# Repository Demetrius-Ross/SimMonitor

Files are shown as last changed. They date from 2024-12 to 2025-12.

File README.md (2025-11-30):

# SimMonitoring Overview WIP
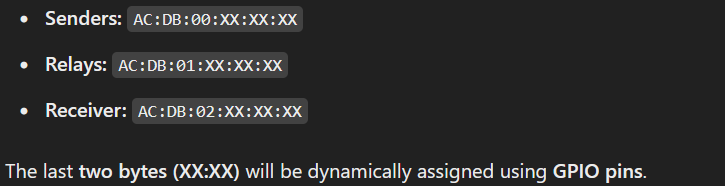
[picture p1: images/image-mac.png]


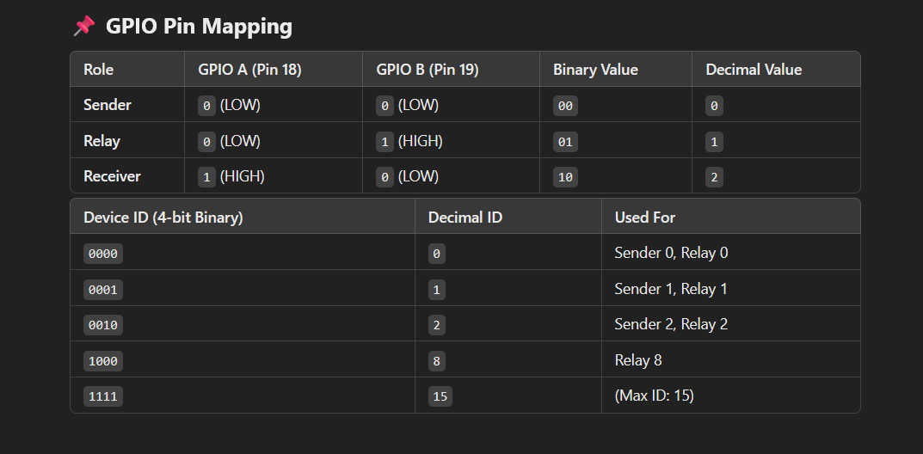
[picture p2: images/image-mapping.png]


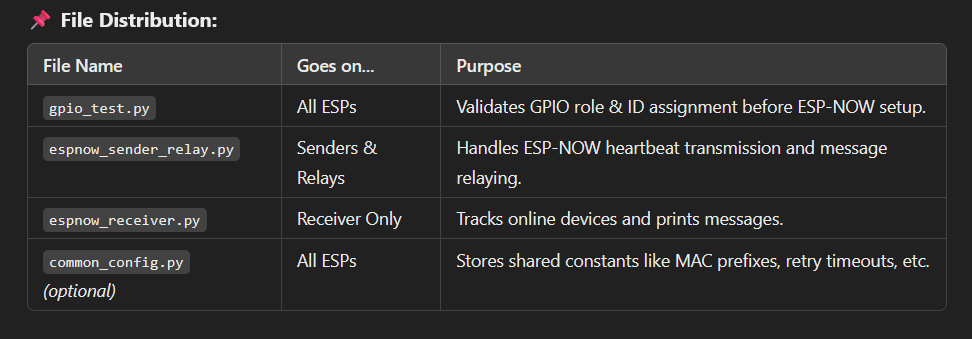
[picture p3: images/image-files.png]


Rename the main script to main.py
'''bash
mv espnow_sender_relay.py main.py
'''

Flash it to the ESP32:
'''bash
mpremote connect /dev/ttyUSB0 fs cp main.py :
'''

Reset the ESP32 to run it automatically:
'''bash
mpremote connect /dev/ttyUSB0 reset
'''

If you want manual execution, you can run any script interactively:
'''bash
mpremote connect /dev/ttyUSB0 run gpio_test.py
'''

## Wiring Guide for Each ESP32 Device

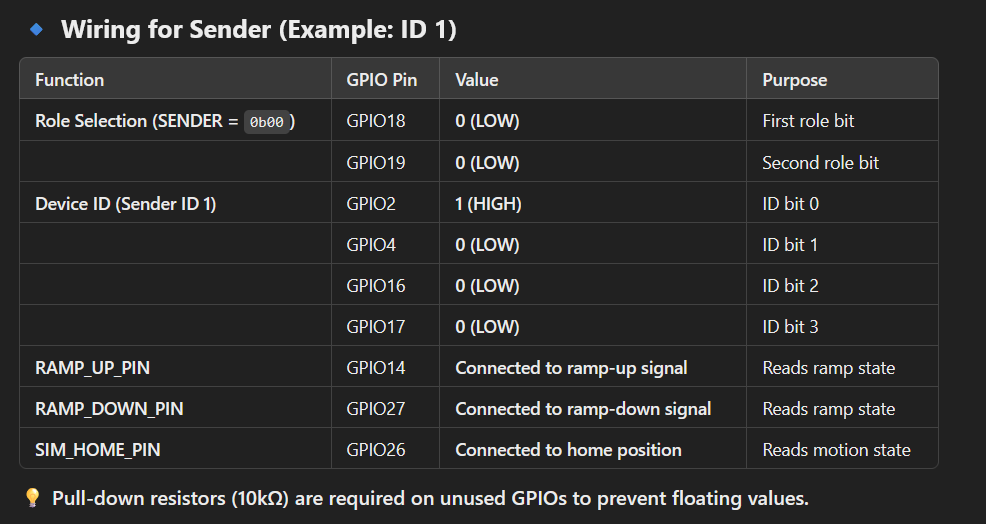
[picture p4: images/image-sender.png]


# ESP32 Device ID Configuration for Sender

Below is a quick reference for how to wire **GPIO17**, **GPIO16**, **GPIO4**, and **GPIO2** to assign a **device ID** (0–15). Each pin is interpreted as a bit in the 4-bit ID, read in the order `(Pin2=bit0, Pin4=bit1, Pin16=bit2, Pin17=bit3)`.

| Device ID | Binary (bit3..bit0) | Pin17 (bit3) | Pin16 (bit2) | Pin4 (bit1) | Pin2 (bit0) |
|---|---|---|---|---|---|
| **0** | `0000` | 0 (LOW) | 0 (LOW) | 0 (LOW) | 0 (LOW) |
| **1** | `0001` | 0 (LOW) | 0 (LOW) | 0 (LOW) | 1 (HIGH) |
| **2** | `0010` | 0 (LOW) | 0 (LOW) | 1 (HIGH) | 0 (LOW) |
| **3** | `0011` | 0 (LOW) | 0 (LOW) | 1 (HIGH) | 1 (HIGH) |
| **4** | `0100` | 0 (LOW) | 1 (HIGH) | 0 (LOW) | 0 (LOW) |
| **5** | `0101` | 0 (LOW) | 1 (HIGH) | 0 (LOW) | 1 (HIGH) |
| **6** | `0110` | 0 (LOW) | 1 (HIGH) | 1 (HIGH) | 0 (LOW) |
| **7** | `0111` | 0 (LOW) | 1 (HIGH) | 1 (HIGH) | 1 (HIGH) |
| **8** | `1000` | 1 (HIGH) | 0 (LOW) | 0 (LOW) | 0 (LOW) |
| **9** | `1001` | 1 (HIGH) | 0 (LOW) | 0 (LOW) | 1 (HIGH) |
| **10** | `1010` | 1 (HIGH) | 0 (LOW) | 1 (HIGH) | 0 (LOW) |
| **11** | `1011` | 1 (HIGH) | 0 (LOW) | 1 (HIGH) | 1 (HIGH) |
| **12** | `1100` | 1 (HIGH) | 1 (HIGH) | 0 (LOW) | 0 (LOW) |
| **13** | `1101` | 1 (HIGH) | 1 (HIGH) | 0 (LOW) | 1 (HIGH) |
| **14** | `1110` | 1 (HIGH) | 1 (HIGH) | 1 (HIGH) | 0 (LOW) |
| **15** | `1111` | 1 (HIGH) | 1 (HIGH) | 1 (HIGH) | 1 (HIGH) |

## Notes

1. **GPIO2** is the **least significant bit** (bit0).  
2. **GPIO17** is the **most significant bit** (bit3).  
3. Use **10kΩ resistors** (or internal pulls) to pull each pin HIGH or LOW.  
4. For a **Sender** role, set **GPIO18 = 0 (LOW)** and **GPIO19 = 0 (LOW)**. This yields `role_value = 0` => `"SENDER"`.

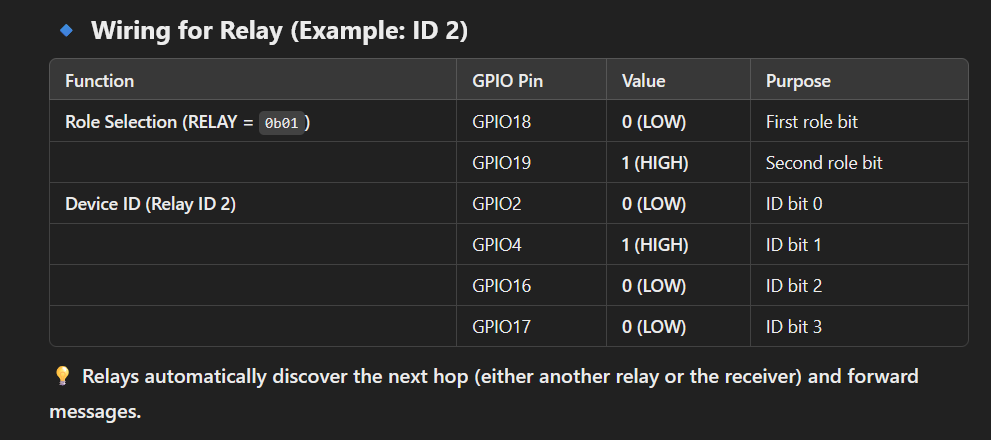
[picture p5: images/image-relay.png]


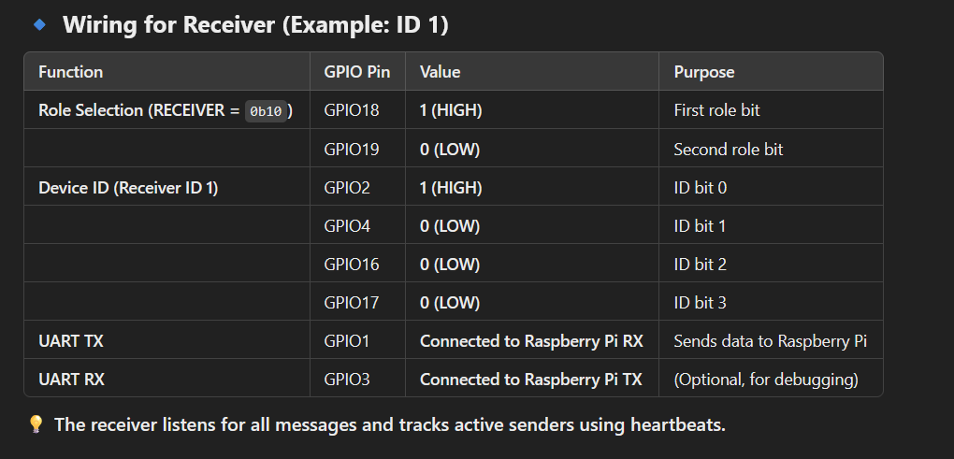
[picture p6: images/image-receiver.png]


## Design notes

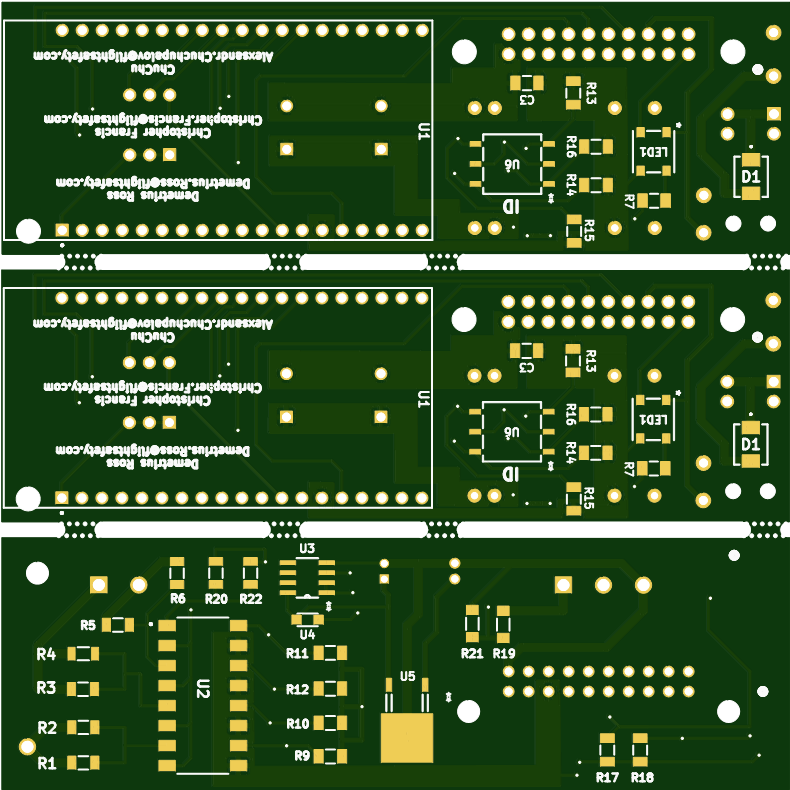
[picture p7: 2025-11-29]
Hardware-Design/gerber-files/panel-boards/Untitled_Combined_Bottom.png

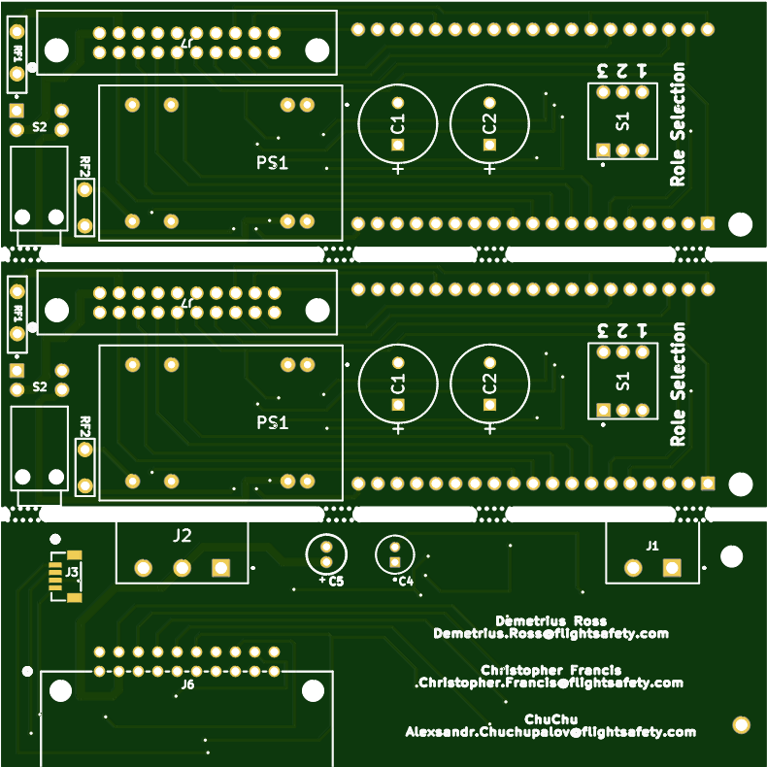
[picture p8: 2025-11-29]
Hardware-Design/gerber-files/panel-boards/Untitled_Combined_Top.png

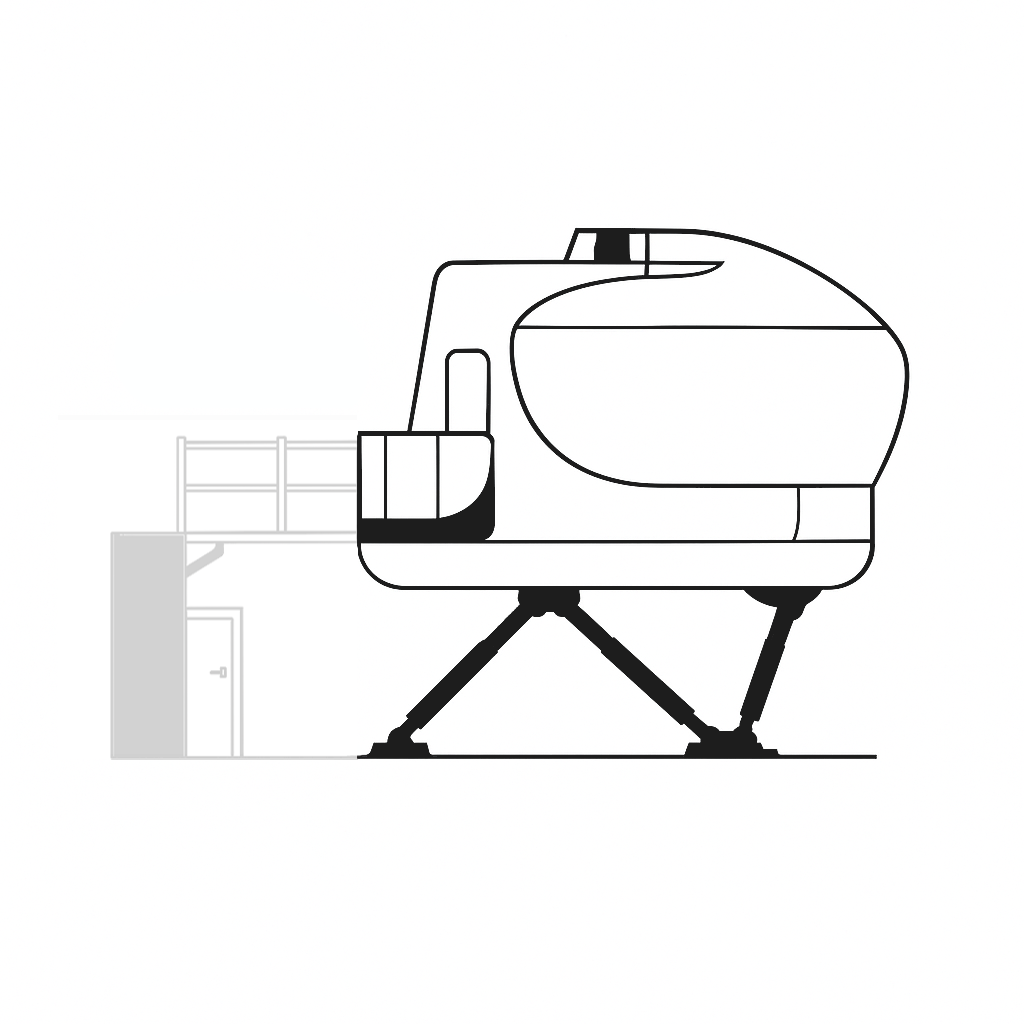
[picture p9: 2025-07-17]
sim_monitor/BACKUP-V1.1/images/FINAL-SIM-DOWN-NO-RAMP.png

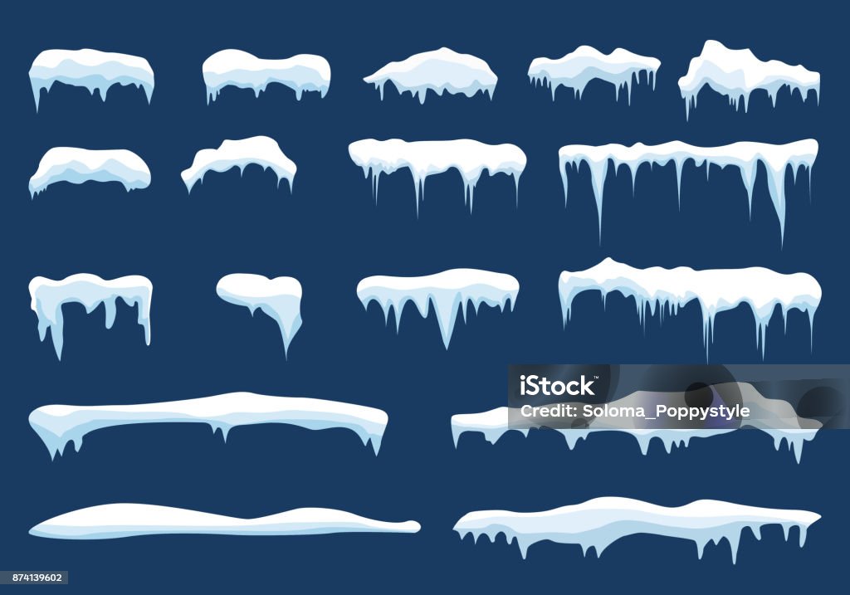
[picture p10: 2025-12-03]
images/istockphoto-874139602-1024x1024.jpg

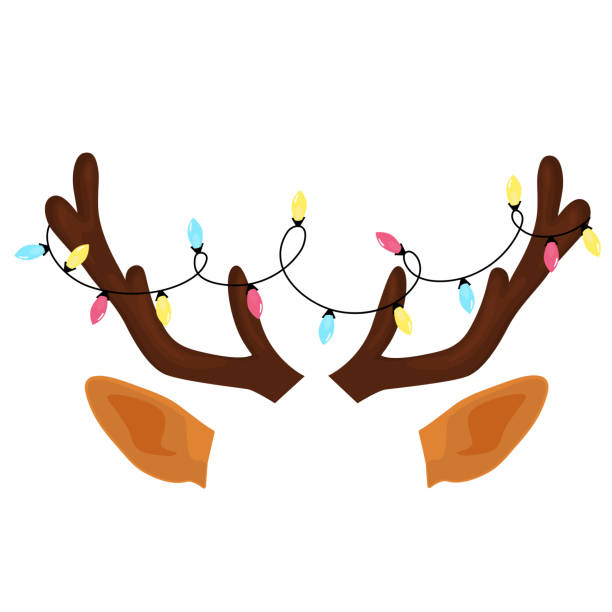
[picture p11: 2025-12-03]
images/istockphoto-1287654583-612x612.jpg

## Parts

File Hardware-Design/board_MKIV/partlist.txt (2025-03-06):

Parts List:
DC-DC Converter: MUS-2405-2N
$4.26
4369-MUS-2405-2N-ND

SMD Version:	
(DC-DC Converter) Buck Switching Regulator IC Positive: MP2315SGJ-Z
$2.92

Schottky Diode: SS14
$0.29

(4 Channel Optocoupler) TLP291-4(GB-TP,E)
$1.42

(24v Ceramic Capacitor) CL31A226KAHNNNE (22)
$0.22

(5v Ceramic Capacitor) CL31B106KAHNNNE 
$0.15

(Decoupling Capacitor) C1206C104K4RACTU (0.1)
Quantity: 2
Total Price: $0.20

Resistors: 

Current-limiting resistors for optocoupler LEDs: CR1206-FX-2200ELF (220Ω)
Quantity: 3
Total Price: $0.30

Pull-down resistors for ESP32 GPIOs: CR1206-FX-1002ELF (10kΩ)
Quantity: 3
Total Price: $0.30

LED current-limiting resistors: CR1206-FX-4700ELF (470Ω)
Quantity: 3
Total Price: $0.30

EN Pin Resistors:

RC1206FR-07499KL (499KΩ)
$0.10

FB Resistor:
RC1206FR-07100KL (100KΩ)
$0.10

CR1206-FX-3002ELF (30KΩ)
$0.10

C1206C104K4RACTU (0.1 µF)
$0.10

Inductor:
HPC 6045NC-4R7M
$0.18

Rotary Switch: RDS-16S-1055-D
$2.41

or 
DRR 3016/RTE1602V44
$3.09/$2.94

=====================================================================================================================================================

Cannon Plug
RS232

2.2k OHM to optocoupler

Component					Value for 5V Output		Purpose
R1 (Feedback Resistor)				40.2kΩ				Sets output voltage
R2 (Feedback Resistor)				7.5kΩ				Sets output voltage
R3 (BST Resistor)				10Ω				Limits bootstrap current
R4 (AAM Resistor 1)				100kΩ				Sets AAM voltage divider
R5 (AAM Resistor 2)				20kΩ				Sets AAM voltage divider
R6 (Optional - Additional FB Tuning Resistor)	20kΩ				Enhances transient response
R7 (EN Voltage Divider Resistor 1)		220kΩ				Steps down 24V to ~1.5V for EN
R8 (EN Voltage Divider Resistor 2)		15kΩ				Works with R7 to set EN voltage
L1 (Inductor)					4.7µH - 10µH, ≥3A		Filters current and maintains switching
C1 (Input Capacitor)				22µF 25V X5R			Stabilizes 24V input
C1A (Input Filter Capacitor)			0.1µF				Reduces input noise
C2 (Output Capacitor)				22µF 25V X7R			Stabilizes 5V output
C2A (Second Output Capacitor)			22µF 25V X7R			Reduces ripple at 5V output
C3 (BST Capacitor)				0.1µF				Provides gate drive voltage boost
C4 (AAM Capacitor)				0.1µF				Smooths AAM voltage
C5 (Compensation Capacitor - Optional)		33pF				Improves transient response
D1 (Bootstrap Diode - Optional)			1N4148				Increases efficiency
D2 (Schottky Diode)				SS14 (40V, 1A)			Provides freewheeling path for current

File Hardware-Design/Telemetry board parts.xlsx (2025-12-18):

MXC6655XA Memsic Inc. | Sensors, Transducers | DigiKey (https://www.digikey.com/en/products/detail/memsic-inc/MXC6655XA/12171923) | $0.94 | 10.00 | 3, 2.7K Ohm, 1, 4.7 MicroFerd Cap | Microsoft Word - MXC6655XA Datasheet Rev A (https://mm.digikey.com/Volume0/opasdata/d220001/medias/docus/495/MXC6655XA_Rev_A_1-22-20.pdf)
TMP112D3IDPWR Texas Instruments | Sensors, Transducers | DigiKey (https://www.digikey.com/en/products/detail/texas-instruments/TMP112D3IDPWR/24768881) | $0.46 |  | 3, 5k resistors and 10 NanoFerd Cap | TMP112x High-Accuracy, Low-Power, Digital Temperature Sensors With SMBus and Two-Wire Serial Interface in SOT563 and X2SON Packages datasheet (Rev. L) (https://www.ti.com/lit/ds/symlink/tmp112.pdf?ts=1626246186568)
ZRE200GE Zilog | Sensors, Transducers | DigiKey (https://www.digikey.com/en/products/detail/zilog/ZRE200GE/5147335) | $1.10 |  | 47K Ohms | PS0402.pdf (https://www.zilog.com/docs/zmotion/PS0402.pdf)
3A0231212A Sensata Technologies | Sensors, Transducers | DigiKey (https://www.digikey.com/en/products/detail/sensata-technologies/3A0231212A/8558165) | $20.00
Amazon.com: GeeekPi GPIO Expansion Module with 3.5inch Screen for Raspberry Pi Pico 1/Pico 1 W and Raspberry Pi Pico 2 Series : Electronics (https://www.amazon.com/GeeekPi-Expansion-Module-3-5inch-Raspberry/dp/B0C98G37PW)
Amazon.com: YELUFT 2 Pack Pre-Soldered ESP32 LoRa V4 Development Board with 915MHz LoRa Antenna, Integrated WiFi Bluetooth SX1262 0.96-inch OLED Display Type C Interface for Meshtastic Arduino : Electronics (https://www.amazon.com/dp/B0FSJLFQTN?sp_csd=d2lkZ2V0TmFtZT1zcF9kZXRhaWw)
STEVAL-STLCS01V1 STMicroelectronics | Development Boards, Kits, Programmers | DigiKey (https://www.digikey.com/en/products/detail/stmicroelectronics/STEVAL-STLCS01V1/7164223)

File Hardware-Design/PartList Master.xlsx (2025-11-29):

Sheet: Sheet1
Sim Monitor Board Component List
Part | DigiKey Name | QTY | Price Per Component | Total Price of Item | Link | Notes
4.7 kOhms Chip Resistor | CRGH1206J4K7 | 8 | $0.14 | $1.12 | CRGH1206J4K7 TE Connectivity Passive Product | Resistors | DigiKey (https://www.digikey.com/en/products/detail/te-connectivity-passive-product/CRGH1206J4K7/2385708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)
10 kOhm Chip Resistor | CR1206-FX-1002ELF | 10 | $0.10 | $1.00 | CR1206-FX-1002ELF Bourns Inc. | Resistors | DigiKey (https://www.digikey.com/en/products/detail/bourns-inc/CR1206-FX-1002ELF/2562678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)
Rotary Hex Switch | DRR3016 | 1 | $3.08 | $3.08 | DRR 3016 Knitter-Switch | Switches | DigiKey (https://www.digikey.com/en/products/detail/knitter-switch/DRR-3016/15296328?s=N4IgTCBcDaICICUEGYAMBGAbCAugXyA)
Optocoupler | 160-1365-5-ND | 1 | $0.90 | $0.90 | LTV-846S Lite-On Inc. | Isolators | DigiKey (https://www.digikey.com/en/products/detail/liteon/LTV-846S/385835?s=N4IgTCBcDaIIwDYAMBaOBmBBWFOByAIiALoC%2BQA)
JST Connector Header | S3B-EH | 1 | $0.11 | $0.11 | S3B-EH JST Sales America Inc. | Connectors, Interconnects | DigiKey (https://www.digikey.com/en/products/detail/jst-sales-america-inc/S3B-EH/926534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)
Schottky Diode | SS34B-HF | 1 | $0.27 | $0.27 | SS34B-HF Comchip Technology | Discrete Semiconductor Products | DigiKey (https://www.digikey.com/en/products/detail/comchip-technology/SS34B-HF/12326213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)
1000 pF (3kV) Ceramic Cap | VPDD302W102K1GV001E | 1 | $0.58 | $0.58 | VPDD302W102K1GV001E Johanson Dielectrics Inc. | Capacitors | DigiKey (https://www.digikey.com/en/products/detail/johanson-dielectrics-inc/VPDD302W102K1GV001E/21283574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)
QWIIC Connector Header | 1568-16766-ND | 1 | $0.75 | $0.75 | 16766 SparkFun Electronics | Connectors, Interconnects | DigiKey (https://www.digikey.com/en/products/detail/sparkfun-electronics/16766/12340136)
JST Female Socket | 455-2935-ND | 1 | $0.18 | $0.18 | 03HR-4K-P-N JST Sales America Inc. | Connectors, Interconnects | DigiKey (https://www.digikey.com/en/products/detail/jst-sales-america-inc/03HR-4K-P-N/1555744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)
47 uF (100V) Electrolytic Cap | UHE2A470MPD | 2 | $0.56 | $1.12 | UHE2A470MPD Nichicon | Capacitors | DigiKey (https://www.digikey.com/en/products/detail/nichicon/UHE2A470MPD/589404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)
D-Sub Female Through Hole | A-DF 09 A/KG-T4S | 1 | $0.72 | $0.72 | A-DF 09 A/KG-T4S Assmann WSW Components | Connectors, Interconnects | DigiKey (https://www.digikey.com/en/products/detail/assmann-wsw-components/A-DF-09-A-KG-T4S/1241802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)
3 Pos Male Block Header | 1757255 | 1 | $1.26 | $1.26 | 1757255 Phoenix Contact | Connectors, Interconnects | DigiKey (https://www.digikey.com/en/products/detail/phoenix-contact/1757255/260475?s=N4IgTCBcDaIIwHYCsCxKSAugXyA)
ISO DC-DC Converter 5V | REC5A-2405SW/H2 | 1 | $14.82 | $14.82 | REC5A-2405SW/H2 Recom Power | Power Supplies - Board Mount | DigiKey (https://www.digikey.com/en/products/detail/recom-power/REC5A-2405SW-H2/6483546)
PTC Reset Fuse 1.1 A | RXEF110-ND | 1 | $0.56 | $0.56 | RXEF110 Littelfuse Inc. | Circuit Protection | DigiKey (https://www.digikey.com/en/products/detail/littelfuse-inc/RXEF110/1045810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) | Backorder
PTC Reset Fuse 500 mA | RXEF050-2HFCT-ND | 1 | $0.54 | $0.54 | RXEF050-2 Littelfuse Inc. | Circuit Protection | DigiKey (https://www.digikey.com/en/products/detail/littelfuse-inc/RXEF050-2/5016000)
ESP32 | ESP32-DEVKITC-32E | 1 | $10 | $10.00 | ESP32-DEVKITC-32E Espressif Systems | Development Boards, Kits, Programmers | DigiKey (https://www.digikey.com/en/products/detail/espressif-systems/ESP32-DEVKITC-32E/12091810)
Total Cost of Components |  |  |  | $37.01
Board Cost (PCB Way @ 10 Boards) |  | QTY: 1 | $0.65
Total |  |  |  | $37.66

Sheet: Sheet2
Part | DigiKey Name | QTY | Price Per Component | Total Price of Item | Link | Notes
Op Amp | TLV272CDR | 10 | $0.71 | $7.06 | TLV272CDR Texas Instruments | Integrated Circuits (ICs) | DigiKey (https://www.digikey.com/en/products/detail/texas-instruments/TLV272CDR/1677979)
1 MOhms ±5% 0.667W, 2/3W Chip Resistor 1206 | ERJ-P08J105V | 50 | $0.05 | $2.36 | ERJ-P08J105V Panasonic Electronic Components | Resistors | DigiKey (https://www.digikey.com/en/products/detail/panasonic-electronic-components/ERJ-P08J105V/525320)
470 Ohms ±1% 0.25W, 1/4W Chip Resistor 1206 | CRG1206F470R | 50 | $0.03 | $1.39 | CRG1206F470R TE Connectivity Passive Product | Resistors | DigiKey (https://www.digikey.com/en/products/detail/te-connectivity-passive-product/CRG1206F470R/2381011)
BAT46W | DIODE SCHOTTKY 100V 150MA SOD123 | 10 | $0.10 | $0.99 | BAT46W Diotec Semiconductor | Discrete Semiconductor Products | DigiKey (https://www.digikey.com/en/products/detail/diotec-semiconductor/BAT46W/13156682)
330 kOhms ±5% 0.667W, 2/3W Chip Resistor 1206 | ERJ-P08J334V | 50 | $0.05 | $2.36 | ERJ-P08J334V Panasonic Electronic Components | Resistors | DigiKey (https://www.digikey.com/en/products/detail/panasonic-electronic-components/ERJ-P08J334V/525379)
10 µF 50 V Aluminum Electrolytic Capacitors Radial | ECA-1HM100 | 10 | $0.12 | $1.21 | ECA-1HM100 Panasonic Electronic Components | Capacitors | DigiKey (https://www.digikey.com/en/products/detail/panasonic-electronic-components/ECA-1HM100/245037)
10 µF 25 V Aluminum Electrolytic Capacitors Radial | 860020472003 | 10 | $0.10 | $1.00 | 860020472003 Würth Elektronik | Capacitors | DigiKey (https://www.digikey.com/en/products/detail/w%C3%BCrth-elektronik/860020472003/5727057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)
Linear Voltage Regulator IC Positive Fixed | BA7815FP-E2 | 10 | $0.77 | $7.72 | BA7815FP-E2 Rohm Semiconductor | Integrated Circuits (ICs) | DigiKey (https://www.digikey.com/en/products/detail/rohm-semiconductor/BA7815FP-E2/2357085)
CONN DIN HDR 20POS | PCN10-20P-2.54DS(72) | 10 | $2.59 | $25.92 | PCN10-20P-2.54DS(72) Hirose Electric Co Ltd | Connectors, Interconnects | DigiKey (https://www.digikey.com/en/products/detail/hirose-electric-co-ltd/PCN10-20P-2-54DS-72/1036416)
CONN DIN RCPT 20POS | PCN13-20S-2.54DSA(71) | 10 | $2.22 | $22.17 | PCN13-20S-2.54DSA(71) Hirose Electric Co Ltd | Connectors, Interconnects | DigiKey (https://www.digikey.com/en/products/detail/hirose-electric-co-ltd/PCN13-20S-2-54DSA-71/1036454)
2 Position Terminal Block Header, Male Pins, Shrouded | 1757242 | 10 | $0.82 | $5.95 | 1757242 Phoenix Contact | Connectors, Interconnects | DigiKey (https://www.digikey.com/en/products/detail/phoenix-contact/1757242/260474)
2 Position Terminal Block Plug, Female Sockets | 1757019 | 10 | $1.69 | $16.88 | 1757019 Phoenix Contact | Connectors, Interconnects | DigiKey (https://www.digikey.com/en/products/detail/phoenix-contact/1757019/260379)
330 mOhms Resistor | CRL1206-FW-R330ELF | 50 | $0.07 | $3.42 | CRL1206-FW-R330ELF Bourns Inc. | Resistors | DigiKey (https://www.digikey.com/en/products/detail/bourns-inc/CRL1206-FW-R330ELF/3785728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)
SWITCH SLIDE DIP SPST 0.025A 24V | DS01C-254-S-03BE | 20 | $0.51 | $10.20 | DS01C-254-S-03BE Same Sky (Formerly CUI Devices) | Switches | DigiKey (https://www.digikey.com/en/products/detail/same-sky-formerly-cui-devices/DS01C-254-S-03BE/11310944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)
SW ROTARY DIP HEX COMP 0.1A 5V | SH-7070TB | 20 | $2.54 | $25.35 | SH-7070TB Nidec Components Corporation | Switches | DigiKey (https://www.digikey.com/en/products/detail/nidec-components-corporation/SH-7070TB/2057875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)
SWITCH PB DPST 3A 30V | PB400EEQR1BLK | 20 | $1.92 | $28.38 | PB400EEQR1BLK E-Switch | Switches | DigiKey (https://www.digikey.com/en/products/detail/e-switch/PB400EEQR1BLK/8042726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)
 |  | Total: | $9.24 | $95.01

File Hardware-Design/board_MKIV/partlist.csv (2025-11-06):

Reference | Qty | Value | Name | Value | Price Per
C1,C5,C6 | 3 | CL31A226KAHNNNE | Ceramic Capacitor | 22 µF | $0.26
C3,C4 | 2 | C1206C104K4RACTU | Ceramic Capacitor | 10 µF | $0.11
D1 | 1 | SS34B-HF | Schottky Diode | 40V @ 3A | $0.27
J1 | 1 | A-DF 09 A/KG-T4S | D-SUB |  | $0.77
L1 | 1 | HPC6045NC-4R7M | Shielded Wirewound Inductor | 4.7 µH | $0.11
R1,R2,R3,R4 | 4 | CRGCQ1206F2K2 | Chip Resistor 1206 | 2.2 kOhms | $0.10
R5,R6,R7,R8,R9,R15,R16,R17 | 8 | CR1206-FX-1002ELF | Chip Resistor 1206 | 10 kOhms | $0.10
R10 | 1 | RC1206FR-07499KL | Chip Resistor 1206 | 499 kOhms | $0.10
R11 | 1 | RMCF1206FT10R0 | Chip Resistor 1206 | 10 Ohms | $0.10
R12 | 1 | RMCF1206FT40K2 | Chip Resistor 1206 | 40.2 kOhms | $0.10
R13 | 1 | RMCF1206FT7K50 | Chip Resistor 1206 | 7.5 kOhms | $0.10
R14 | 1 | CRCW120620K0FKEAC | Chip Resistor 1206 | 20 kOhms | $0.10
S1 | 1 | DRR3016 | Rot Switch | 16 Pos Hex | $3.09
U1 | 1 | ESP32-DEVKITC-32D | ESP32
U2 | 1 | LTV-846S | Optocoupler | 4-Channel | $1.07
U4 | 1 | MP2315SGJ-Z | Buck Converter |  | $2.92
 | Aa 1111111111111111111111

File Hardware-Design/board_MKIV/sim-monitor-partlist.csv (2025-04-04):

Reference | Qty | Serial Number | Name | Value | Price Per | Price Total
C1,C5,C6 | 3 | CL31A226KAHNNNE | Ceramic Capacitor | 22 µF | $0.26 | $0.78
C2,C3 | 2 | CL31B106KAHNNNE | Ceramic Capacitor | 10 µF | $0.11 | $0.22
D1 | 1 | SS34B-HF | Schottky Diode | 40V @ 3A | $0.27 | $0.27
J1 | 1 | A-DF 09 A/KG-T4S | D-SUB |  | $0.77 | $0.77
R1,R2,R3,R4 | 4 | CRGCQ1206F2K2 | Chip Resistor 1206 | 2.2 kOhms | $0.10 | $0.40
R5,R6,R7,R8,R9,R15,R16,R17 | 8 | CR1206-FX-1002ELF | Chip Resistor 1206 | 10 kOhms | $0.10 | $0.80
R10 | 1 | RC1206FR-07499KL | Chip Resistor 1206 | 499 kOhms | $0.10 | $0.10
R11 | 1 | RMCF1206FT10R0 | Chip Resistor 1206 | 10 Ohms | $0.10 | $0.10
R12 | 1 | RMCF1206FT40K2 | Chip Resistor 1206 | 40.2 kOhms | $0.10 | $0.10
R13 | 1 | RMCF1206FT7K50 | Chip Resistor 1206 | 7.5 kOhms | $0.10 | $0.10
R14 | 1 | CRCW120620K0FKEAC | Chip Resistor 1206 | 20 kOhms | $0.10 | $0.10
S1 | 1 | DRR3016 | Rot Switch | 16 Pos Hex | $3.09 | $3.09
U1 | 1 | ESP32-DEVKITC-32D | ESP32 |  | $8.00 | $8.00
U2 | 1 | LTV-846S | Optocoupler | 4-Channel | $1.07 | $1.07
U4 | 1 | MP2315SGJ-Z | DC-DC |  | $2.92 | $13.40
 | 1 | RA111C1021-116 | On-Off Switch |  | $1.57 | $1.57
PCB |  |  |  |  |  | $15.05
 |  |  |  |  |  | Total
 |  |  |  |  |  | $45.92

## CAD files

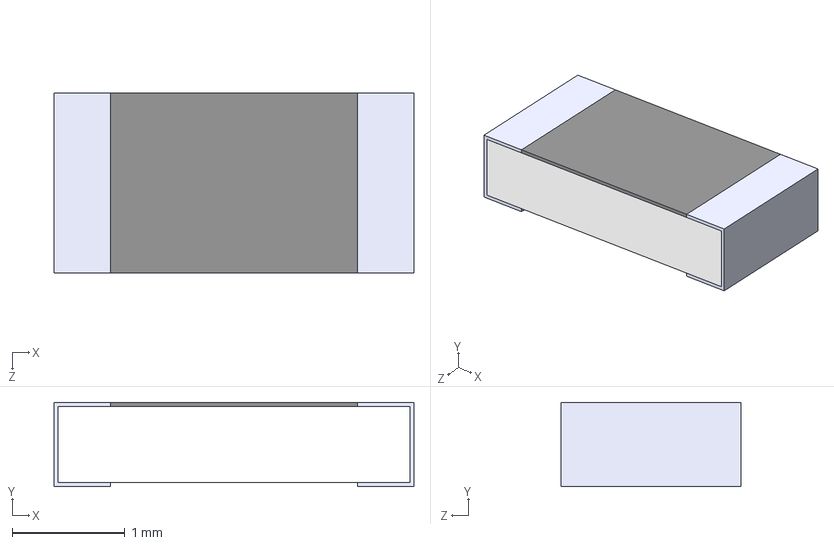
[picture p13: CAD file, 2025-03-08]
board_design/models/CR1206_FX_1002ELF/CR1206-FX-1002ELF.step
3.20 x 0.75 x 1.60 mm

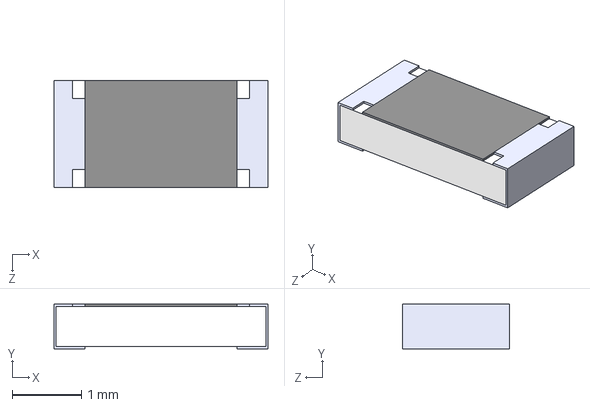
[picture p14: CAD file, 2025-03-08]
board_design/models/CRGCQ1206F2K2/CRGCQ1206F2K2.step
3.10 x 0.65 x 1.55 mm

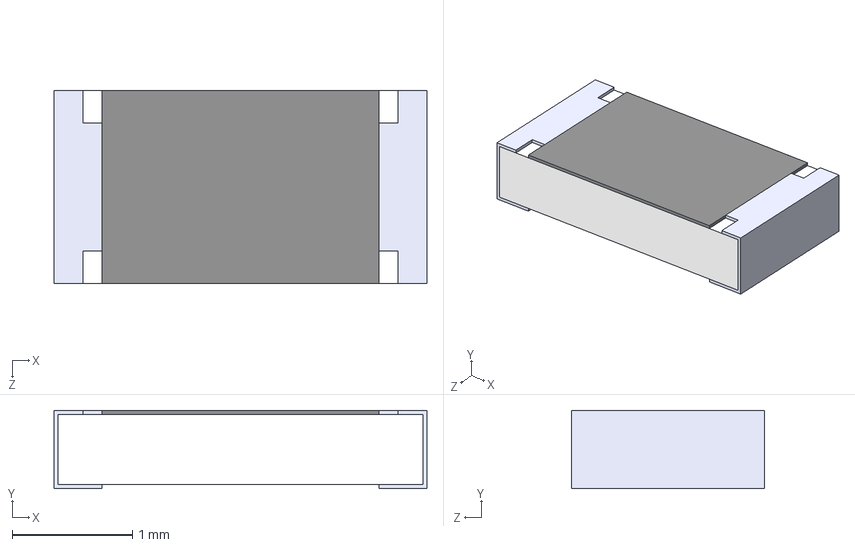
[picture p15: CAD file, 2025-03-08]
board_design/models/RC1206FR_07100KL/RC1206FR-07100KL.step
3.10 x 0.65 x 1.60 mm

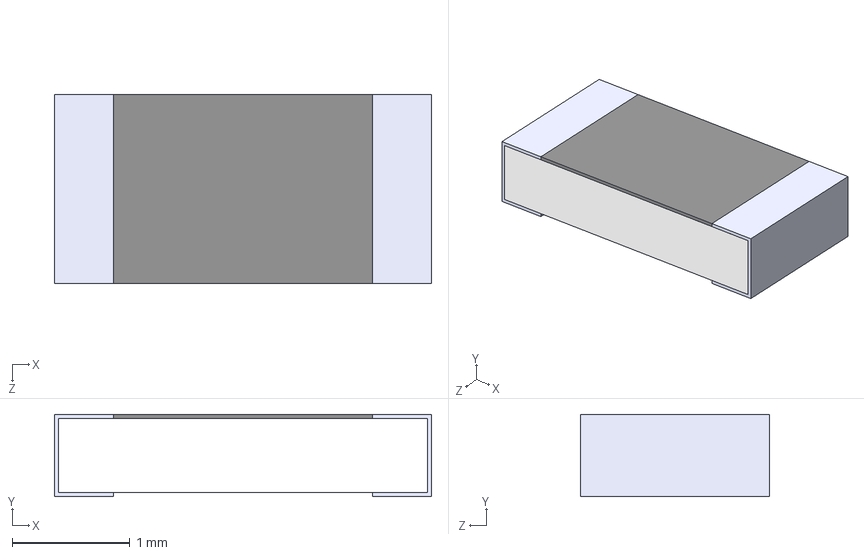
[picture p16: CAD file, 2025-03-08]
board_design/models/RMCF1206FT10R0/RMCF1206FT10R0.step
3.20 x 0.7 x 1.60 mm

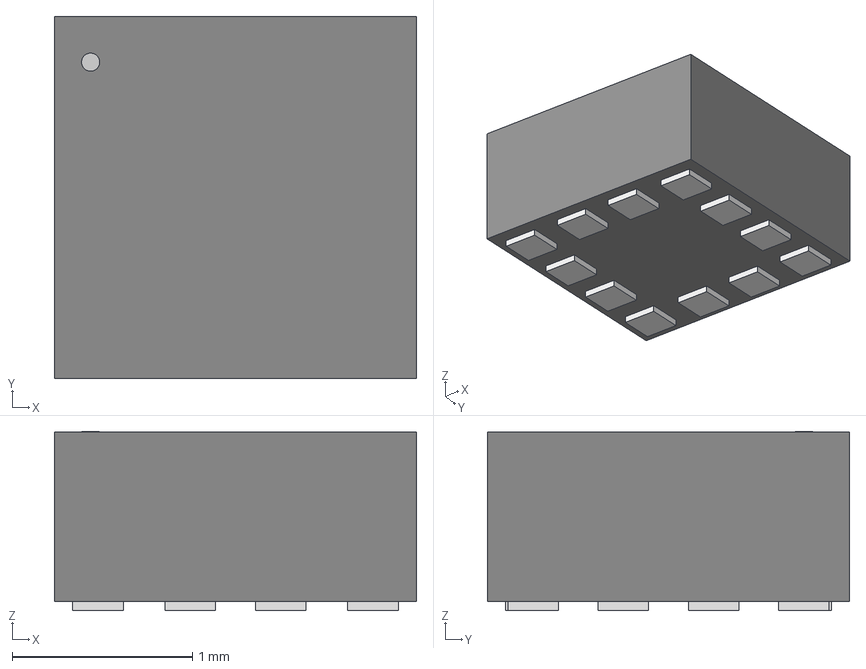
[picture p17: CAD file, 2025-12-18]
Hardware-Design/AllModels/MXC6655XA_MEM.step
2.01 x 2.01 x 0.993 mm

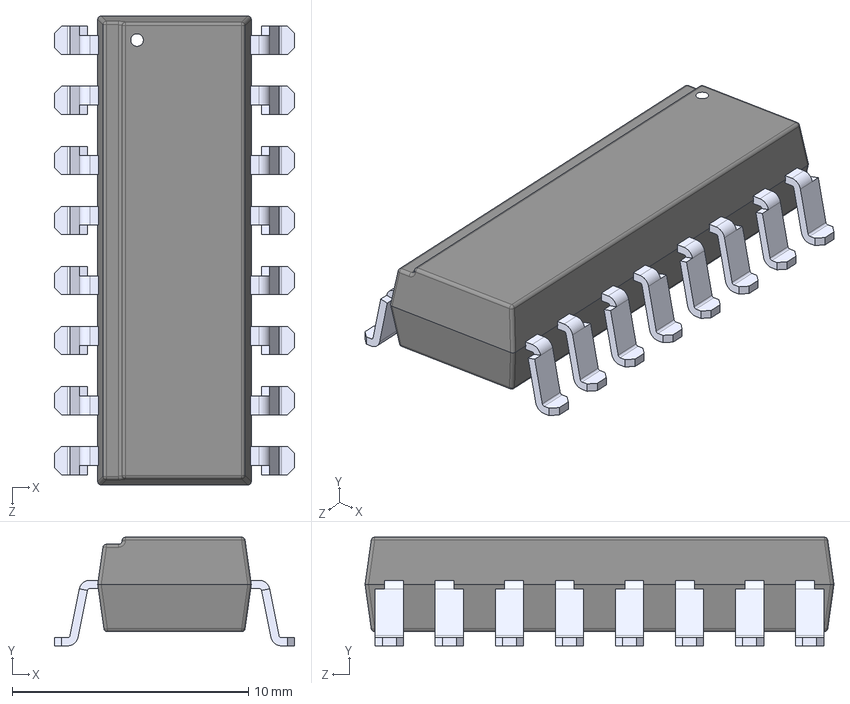
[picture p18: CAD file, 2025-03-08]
Hardware-Design/board_MKIV/models/LTV_846S/LTV-846S.step
10.2 x 4.60 x 19.8 mm

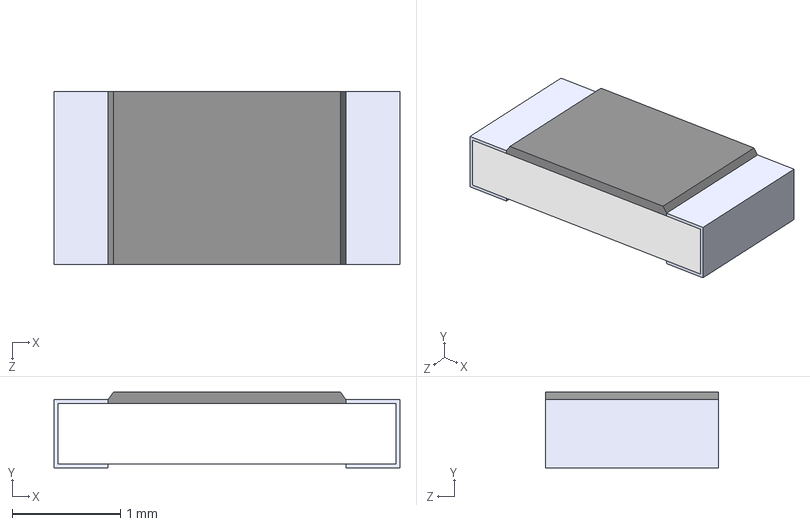
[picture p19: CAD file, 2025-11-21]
Hardware-Design/board_MKIV/models/model/CRL1206-FW-R330ELF.step
3.20 x 0.7 x 1.60 mm

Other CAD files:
Hardware-Design/AllModels/1757255.stp
Hardware-Design/AllModels/1770979.step
Hardware-Design/AllModels/1989764.step
Hardware-Design/AllModels/20_pin_90.STEP
Hardware-Design/AllModels/20_pin_straight.STEP
Hardware-Design/AllModels/A-DF_09_A_KG-T4S.step
Hardware-Design/AllModels/BAT46W.step
Hardware-Design/AllModels/C1206C104K4RACTU.step
Hardware-Design/AllModels/CRCW120620K0FKEAC.step
Hardware-Design/AllModels/D0008A.stp
Hardware-Design/AllModels/DS01C-254-S-03BE.step
Hardware-Design/AllModels/ECA1HM100.step
Hardware-Design/AllModels/ERJ-P08J334V.step
Hardware-Design/AllModels/ERJP08J105V.step
Hardware-Design/AllModels/MP2315GJ-Z.STEP
Hardware-Design/AllModels/PB400EEQR1BLK.step
Hardware-Design/AllModels/PCAP_10x12_5-THRU-ELECT_NCA.step
Hardware-Design/AllModels/REC5A-2405SW_H2.step
Hardware-Design/AllModels/RNCP1206FTD1K10.step
Hardware-Design/AllModels/S3B-EH.STEP
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

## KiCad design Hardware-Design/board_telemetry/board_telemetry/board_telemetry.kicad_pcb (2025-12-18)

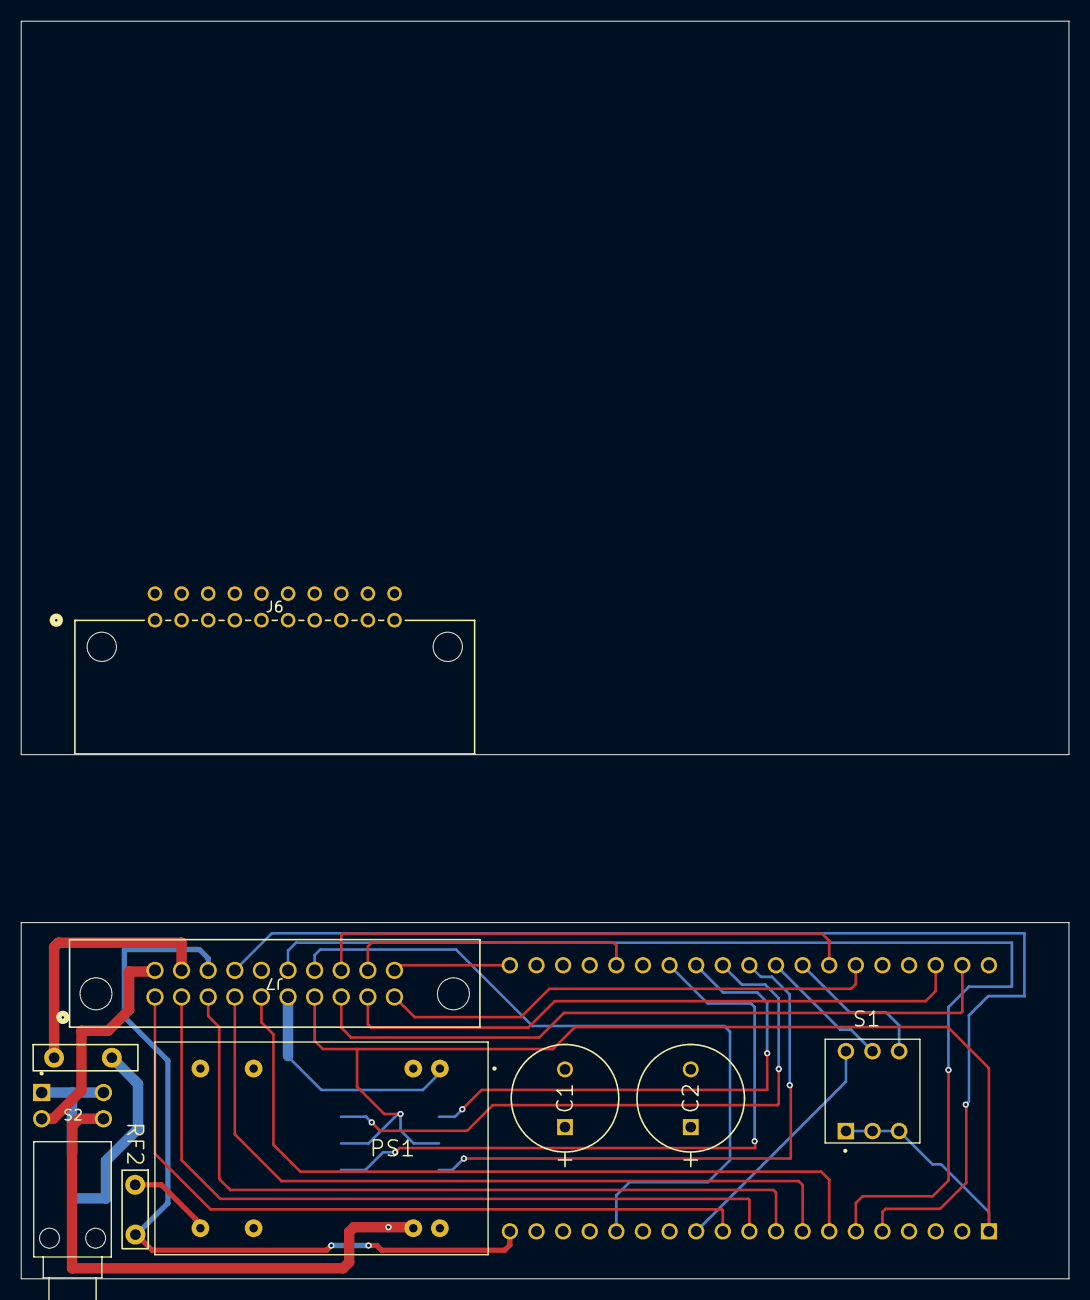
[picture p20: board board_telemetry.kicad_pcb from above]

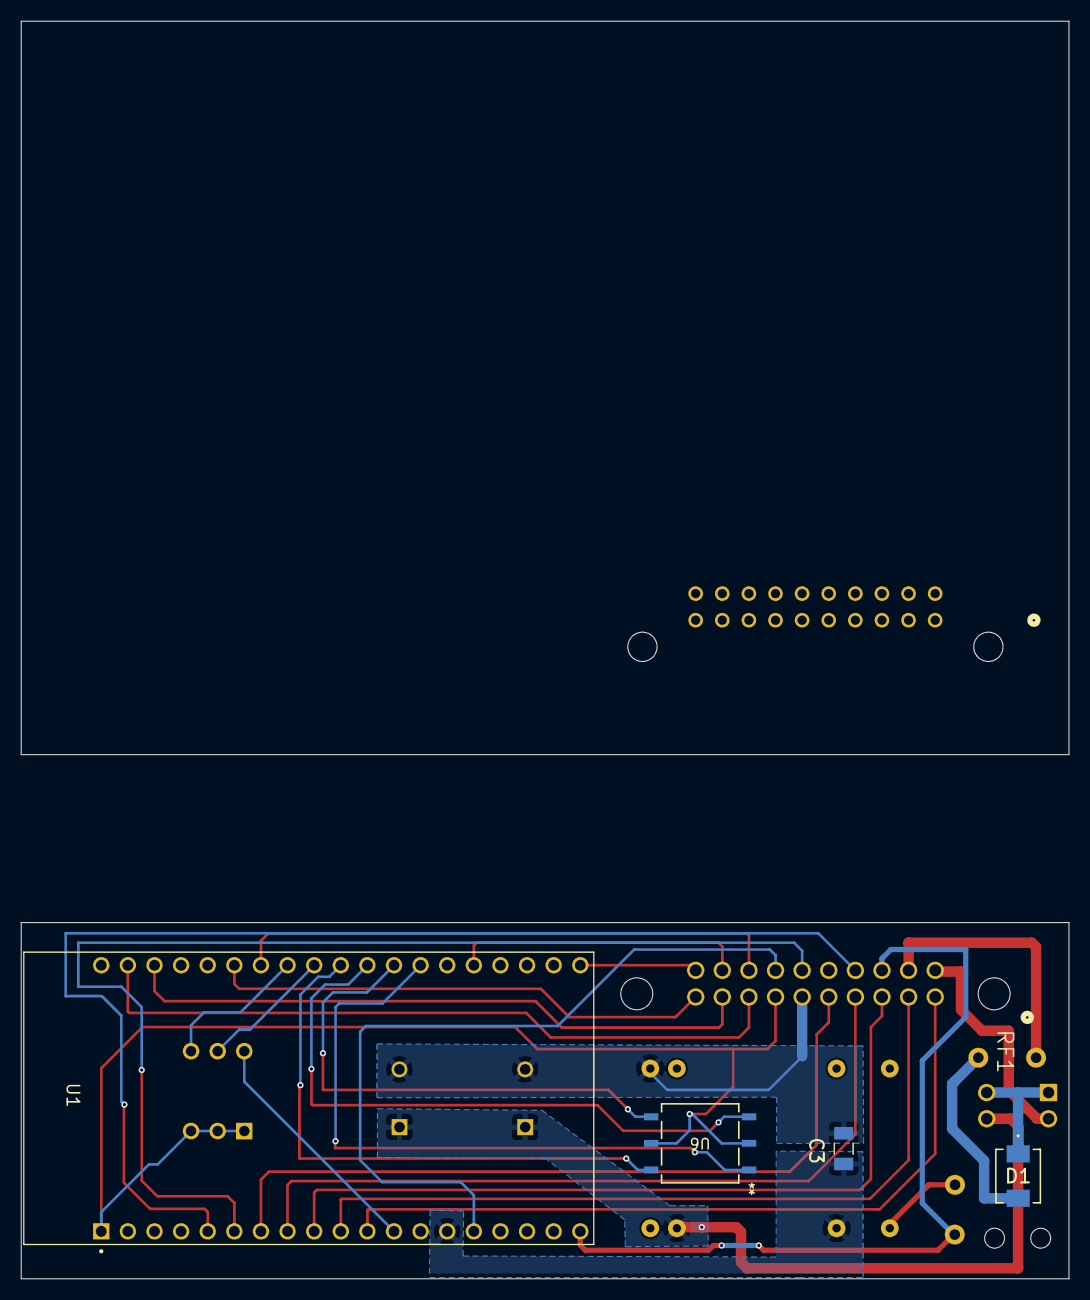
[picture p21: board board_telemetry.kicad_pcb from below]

Board: 2 copper layers, 100.0 x 34.0 mm, 13 parts (4 on the bottom side), 28 nets.

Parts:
C1, C2: UHE2A470MPD; PCAP_10x12_5-THRU-ELECT_NCA
C3: 1000pf/3kV; CAPC3216X180N
D1: SS34B-HF; DO214AASMB_CIP-L
J6: 20_pin_90
J7: 20-pin-straight; 20_pin_straight
PS1: REC5A-2405SW_H2; CONV_REC5A-2405SW_H2
RF1, RF2: PTC_RESET_FUSE
S1: DS01C-254-S-03BE; SW_DS01C-254-S-03BE
S2: PB400EEQR1BLK; SW_PB400EEQR1BLK
U1: ESP32-DEVKITC-32D; MODULE_ESP32-DEVKITC-32D
U6: SH-7070TB; SH-7070TB_7P1X7P3_NDC

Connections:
+3.3V: J6.B7, J7.7, S1.1A, S1.2A, S1.3A, U1.J2-1 (3V3), U6.2, U6.5
+24V: D1.1, S2.1, S2.3
+VIN: C1.1, C2.1, D1.2, J6.A1, J7.11, PS1.22 (+VIN), RF1.2, S2.2, S2.4
+VIN-dc: J6.A2, J7.12, RF1.1
+VOUT_esp_signal: J6.A3, J7.13, RF2.2, U1.J2-19 (EXT_5V)
-Vin: C1.2, C2.2, C3.2, J6.B6, J7.6, PS1.2 (-VIN)
/+VOUT: PS1.14 (+VOUT), RF2.1
CLK: J6.A10, J7.20, U1.J3-19 (CLK)
ESP_GND2: C3.1, J6.A8, J7.18, PS1.16 (-VOUT), U1.J2-14 (GND1), U1.J3-1 (GND3), U1.J3-7 (GND2)
GPIO_2: J6.A9, J7.19, U1.J3-15 (IO2)
GPIO_4: U1.J3-13 (IO4), U6.1
GPIO_5: U1.J3-10 (IO5), U6.6
GPIO_13: J6.A7, J7.17, U1.J2-15 (IO13)
GPIO_14: S1.1B, U1.J2-12 (IO14)
GPIO_16: U1.J3-12 (IO16), U6.4
GPIO_17: U1.J3-11 (IO17), U6.3
GPIO_18: S1.2B, U1.J3-9 (IO18)
GPIO_19: S1.3B, U1.J3-8 (IO19)
GPIO_21: J6.B10, J7.10, U1.J3-6 (IO21)
GPIO_22: J6.B9, J7.9, U1.J3-3 (IO22)
GPIO_23: J6.B8, J7.8, U1.J3-2 (IO23)
GPIO_25: J6.B3, J7.3, U1.J2-9 (IO25)
GPIO_26: J6.B2, J7.2, U1.J2-10 (IO26)
GPIO_27: J6.B1, J7.1, U1.J2-11 (IO27)
GPIO_32: J6.B5, J7.5, U1.J2-7 (IO32)
GPIO_33: J6.B4, J7.4, U1.J2-8 (IO33)
GPIO_ANAG_34: J6.A4, J7.14, U1.J2-5 (IO34)
GPIO_ANAG_35: J6.A6, J7.16, U1.J2-6 (IO35)

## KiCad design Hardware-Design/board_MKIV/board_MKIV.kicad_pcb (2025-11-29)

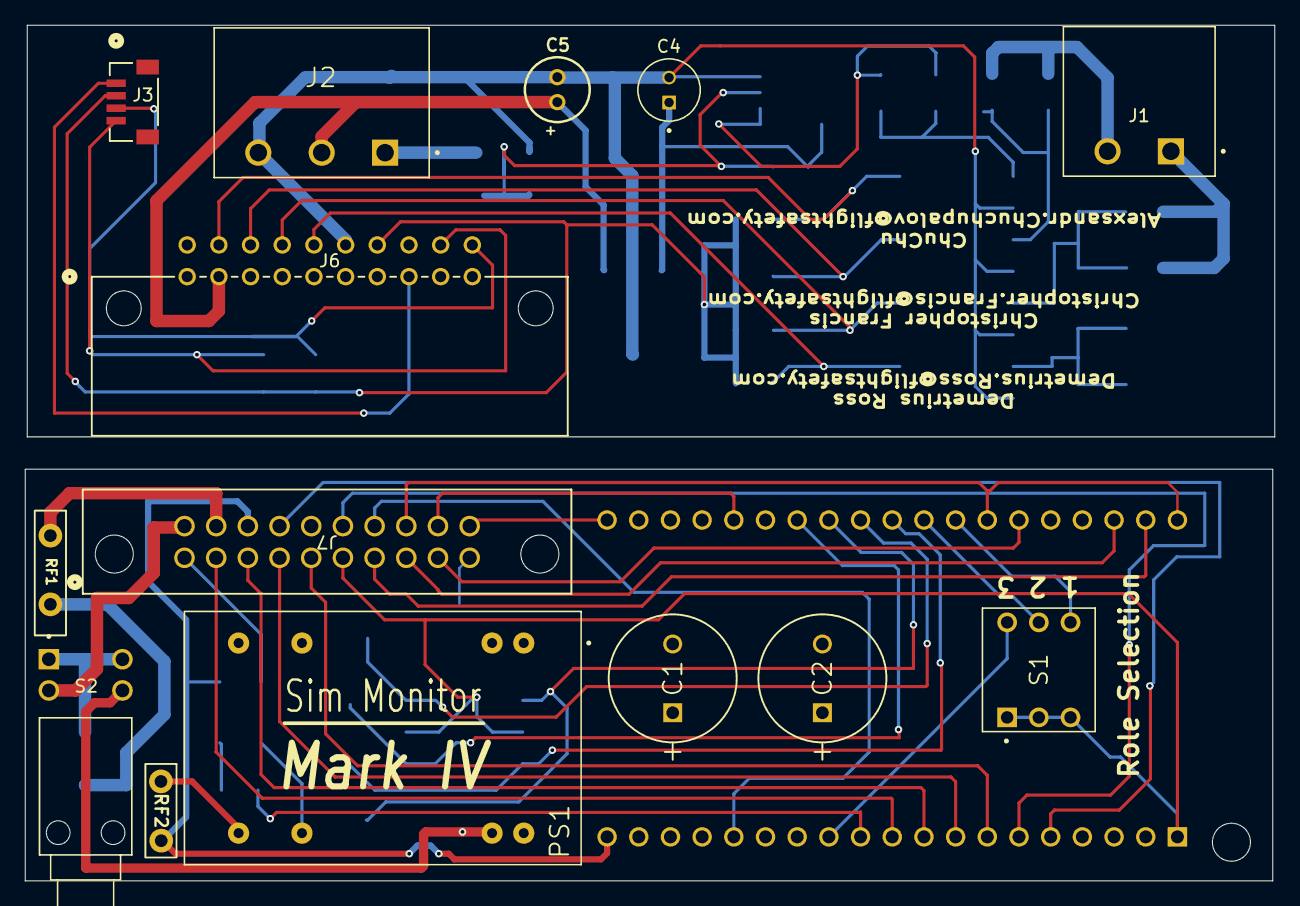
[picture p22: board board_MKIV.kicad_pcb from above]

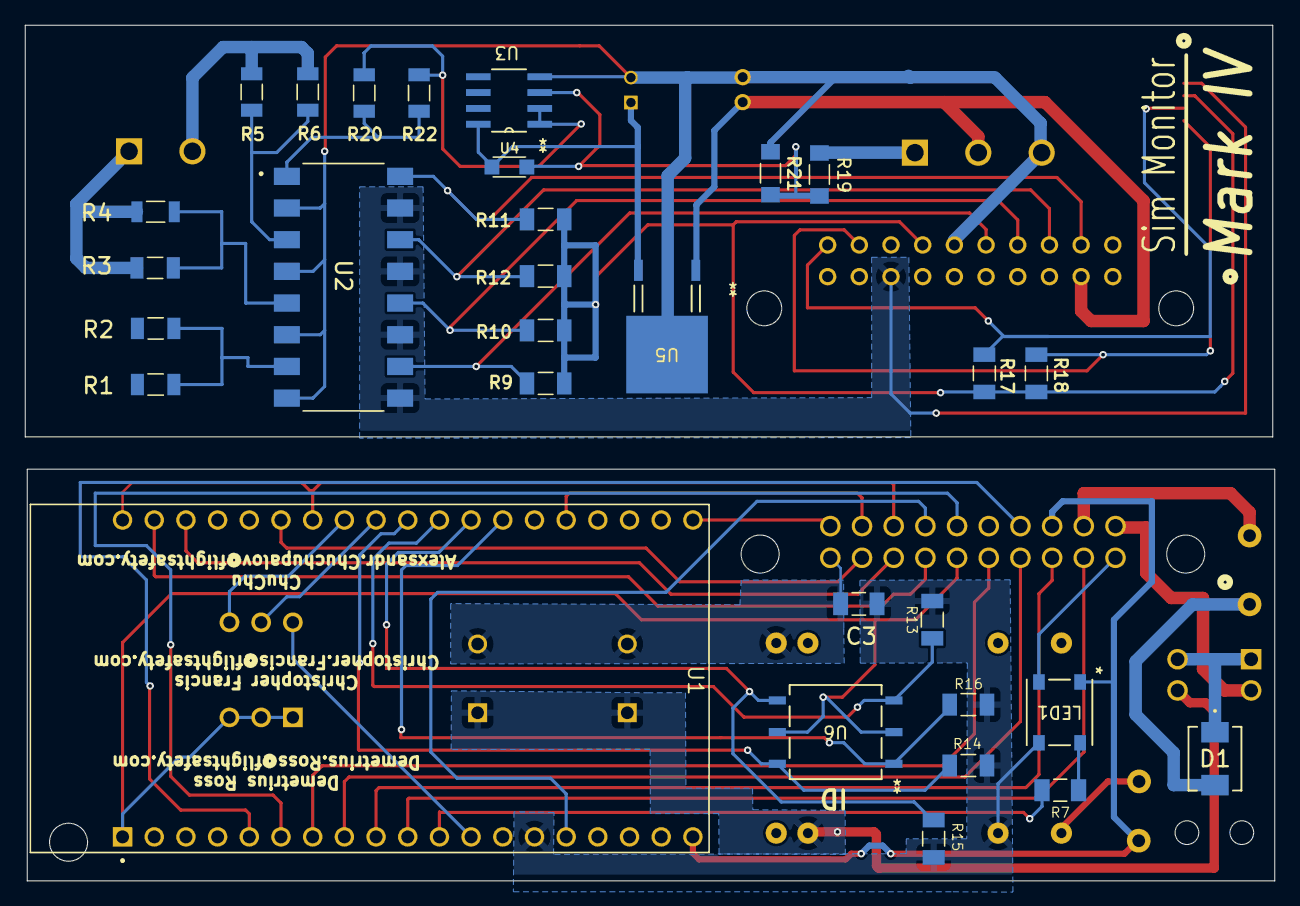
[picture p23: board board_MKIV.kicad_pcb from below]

Board: 2 copper layers, 100.2 x 68.6 mm, 44 parts (30 on the bottom side), 40 nets.

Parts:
C1, C2: UHE2A470MPD; PCAP_10x12_5-THRU-ELECT_NCA
C3: 1000pf/3kV; CAPC3216X180N
C4: ECA1HM100; CAPPRD200W50D500H1100
C5: WCAP-ATG5_5X11; WCAP-ATG5_5X11_DXL_
D1: SS34B-HF; DO214AASMB_CIP-L
J1: 1757242; PHOENIX_1757242
J2: jst-power; PHOENIX_1757255
J3: JST -SM; CONN_BM04B-SRSS-TB_SPK
J6: 20_pin_90
J7: 20-pin-straight; 20_pin_straight
LED1: COM-16347; COM-16347_SPK
PS1: REC5A-2405SW_H2; CONV_REC5A-2405SW_H2
R1, R2, R3, R5, R6: CRGH1206J4K7; RESC3115X65N
R4: CRGH1206J4K7; RESC3015X65N
R7: CRL1206-FW-R330ELF; RESC3216X70N
R9, R10, R11, R12, R13, R14, R15, R16, R17, R18: CR1206-FX-1002ELF; RESC3216X75N
R19: ERJP08J105V; RES_ERJP08J105V
R20, R22: CRG1206F470R; RESC3115X65N
R21: ERJP08J334V; RES_ERJP08J334V
RF1, RF2: PTC_RESET_FUSE
S1: DS01C-254-S-03BE; SW_DS01C-254-S-03BE
S2: PB400EEQR1BLK; SW_PB400EEQR1BLK
U1: ESP32-DEVKITC-32D; MODULE_ESP32-DEVKITC-32D
U2: LTV-846S; SOIC254P1016X460-16N
U3: TLV272CDR; D8
U4: BAT46W; SOD123F
U5: BA&; TO252-3_ROM
U6: SH-7070TB; SH-7070TB_7P1X7P3_NDC

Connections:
+3.3V: J3.2, J6.B7, J7.6, R9.2, R10.2, R11.2, R12.2, R17.1, R18.1, S1.1A, S1.2A, S1.3A, U1.J2-1 (3V3), U6.2, U6.5
+24V: D1.1, S2.1, S2.3
+VIN: C1.1, C2.1, D1.2, J6.A1, J7.11, PS1.22 (+VIN), RF1.2, S2.2, S2.4
+VIN-dc: C5.1, J2.02, J6.A2, J7.12, RF1.1, U5.1 (INPUT)
+VOUT_esp_signal: J6.A3, J7.13, LED1.1 (VDD), RF2.2, U1.J2-19 (EXT_5V)
-Vin: C1.2, C2.2, C3.2, C4.N, C5.2, J2.03, J6.B6, J7.10, PS1.2 (-VIN), R21.1, U2.2, U2.4, U2.6, U2.8, U3.4 (GND), U5.2 (Common)
/ESP-Board/+VOUT: PS1.14 (+VOUT), RF2.1
/ramp_down_opto: R5.2, R6.2, U2.3
/sim_home_opto: R20.2, R22.2, U2.1
CLK: J6.A10, J7.20, U1.J3-19 (CLK)
ESP_GND2: C3.1, J3.1, J6.A8, J7.18, LED1.3 (VSS), PS1.16 (-VOUT), R13.2, R14.2, R15.2, R16.2, U1.J2-14 (GND1), U1.J3-1 (GND3), U1.J3-7 (GND2), U2.9, U2.11, U2.13, U2.15
GPIO_2: J6.A9, J7.19, U1.J3-15 (IO2)
GPIO_4: R16.1, U1.J3-13 (IO4), U6.1
GPIO_5: R14.1, U1.J3-10 (IO5), U6.6
GPIO_13: J6.A7, J7.17, U1.J2-15 (IO13)
GPIO_14: S1.1B, U1.J2-12 (IO14)
GPIO_16: R15.1, U1.J3-12 (IO16), U6.4
GPIO_17: R13.1, U1.J3-11 (IO17), U6.3
GPIO_18: S1.2B, U1.J3-9 (IO18)
GPIO_19: S1.3B, U1.J3-8 (IO19)
GPIO_21: J3.3, J6.B10, J7.9, R17.2, U1.J3-6 (IO21)
GPIO_22: J3.4, J6.B9, J7.8, R18.2, U1.J3-3 (IO22)
GPIO_23: J6.B8, J7.7, U1.J3-2 (IO23)
GPIO_25: J6.B3, J7.3, R12.1, U1.J2-9 (IO25), U2.14
GPIO_26: J6.B2, J7.2, R11.1, U1.J2-10 (IO26), U2.16
GPIO_27: J6.B1, J7.1, LED1.2 (DOUT), R7.2, U1.J2-11 (IO27)
GPIO_32: J6.B5, J7.5, R9.1, U1.J2-7 (IO32), U2.10
GPIO_33: J6.B4, J7.4, R10.1, U1.J2-8 (IO33), U2.12
GPIO_ANAG_34: J6.A4, J7.14, U1.J2-5 (IO34)
GPIO_ANAG_35: J6.A6, J7.16, U1.J2-6 (IO35)
unnamed: LED1.4 (DIN), R7.1
unnamed: R19.1, R21.2, U3.3 (1IN+), U4.2
VDD: C4.P, U3.8 (VDD), U4.1, U5.3 (OUTPUT)
ramp_down: J1.02, R5.1, R6.1
ramp_up: J1.01, R3.1, R4.1
ramp_up_opto: R3.2, R4.2, U2.5
sim_home: J2.01, R19.2
sim_home_safe: R20.1, R22.1, U3.1 (1OUT), U3.2 (1IN-)
spare: R1.1, R2.1
spare_opto: R1.2, R2.2, U2.7

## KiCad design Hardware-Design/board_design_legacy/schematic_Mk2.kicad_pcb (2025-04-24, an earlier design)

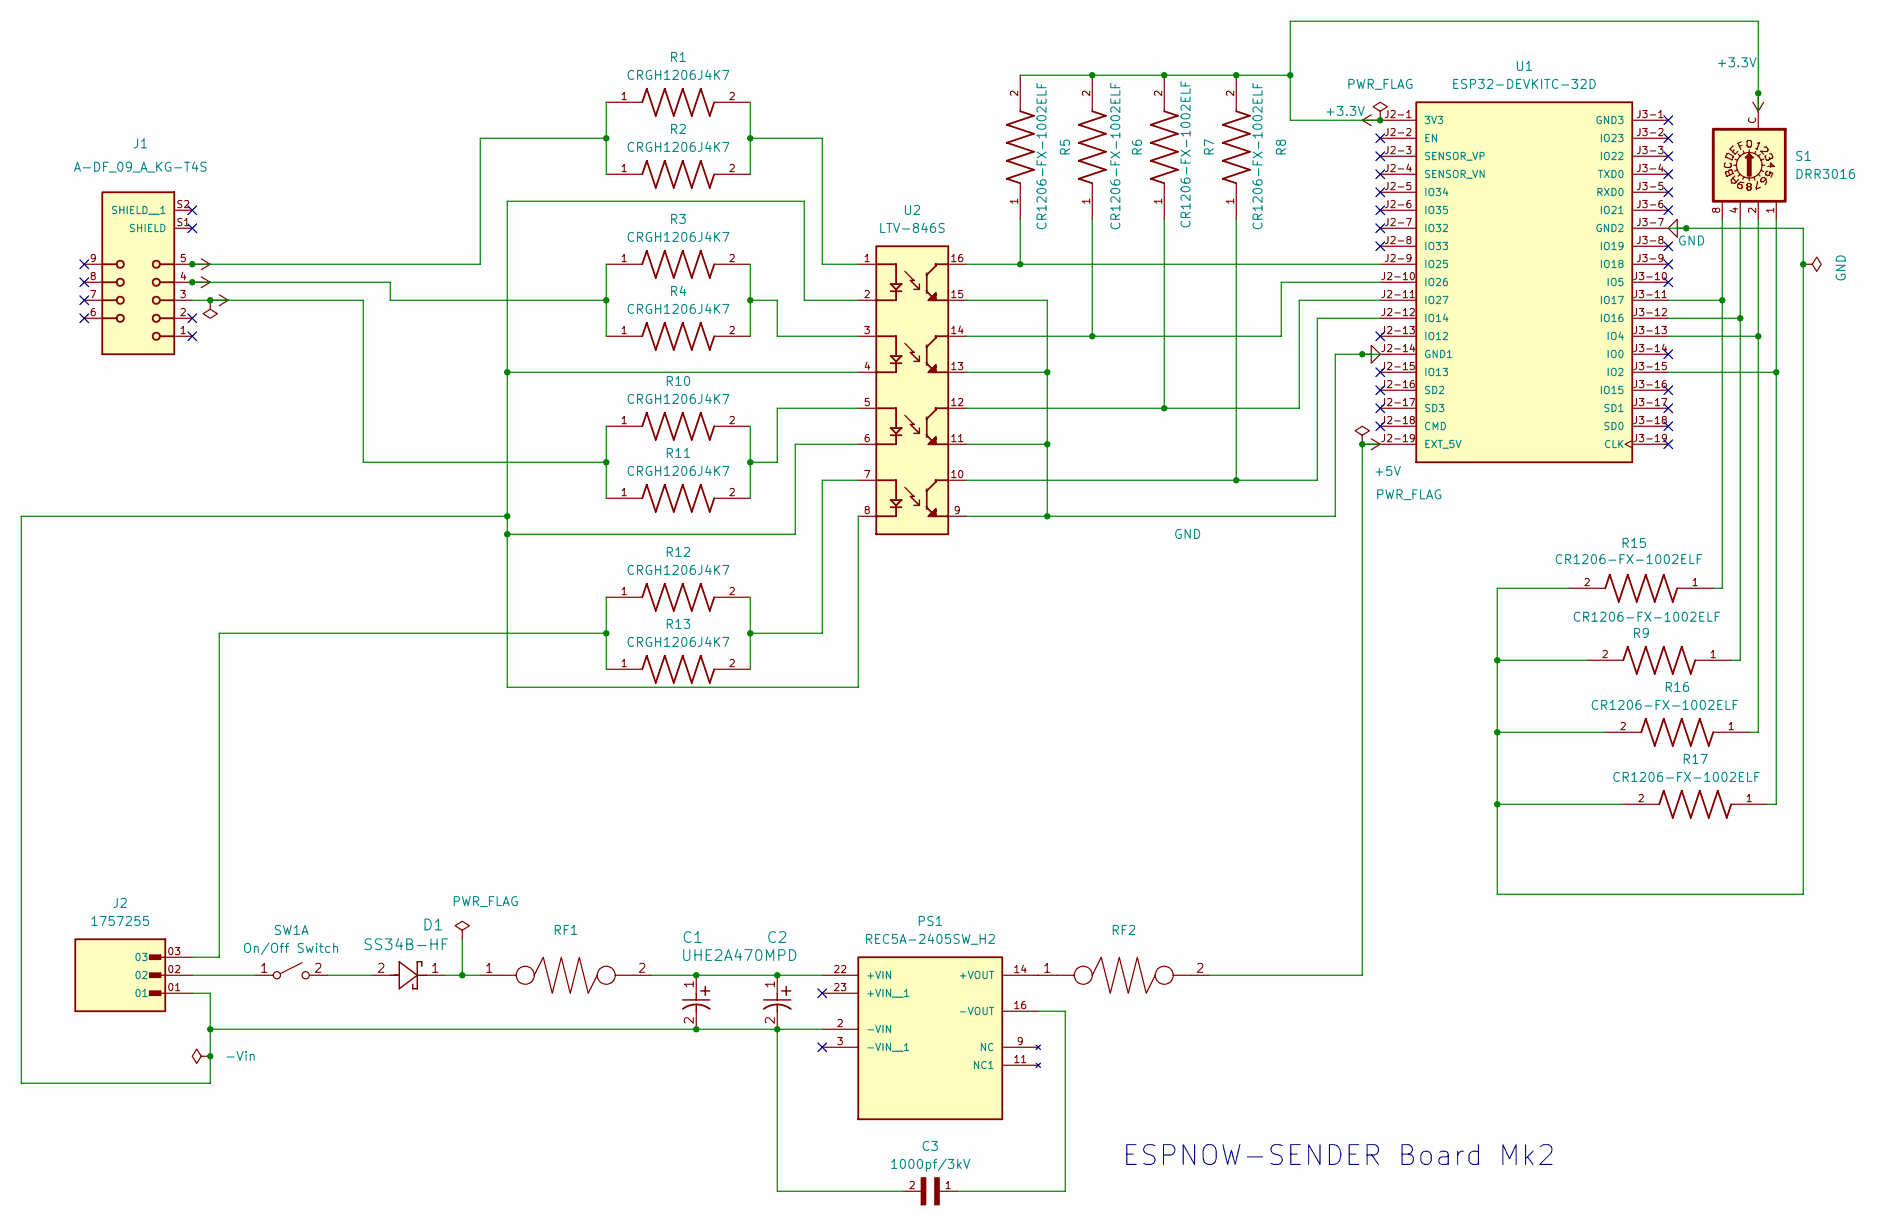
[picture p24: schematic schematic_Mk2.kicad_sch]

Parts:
C1, C2: UHE2A470MPD; PCAP_10x12_5-THRU-ELECT_NCA
C3: 1000pf/3kV; CAPC3216X180N
D1: SS34B-HF; DO214AASMB_CIP-L
J1: A-DF_09_A_KG-T4S; ASSMANN_A-DF_09_A_KG-T4S; PARTREV 05
J2: 1757255; PHOENIX_1757255; PARTREV 28.07.2023
PS1: REC5A-2405SW_H2; CONV_REC5A-2405SW_H2; PARTREV N/A
R1, R2, R3, R10, R11, R12, R13: CRGH1206J4K7; RESC3115X65N
R4: CRGH1206J4K7; RESC3015X65N
R5, R6, R7, R8, R9, R15, R16, R17: CR1206-FX-1002ELF; RESC3216X75N
RF1, RF2: PTC_RESET_FUSE
S1: DRR3016; DRR3010; MPN DRR3016
SW1: On/Off Switch; Panasonic_EVQPUJ_EVQPUA
U1: ESP32-DEVKITC-32D; MODULE_ESP32-DEVKITC-32D; PARTREV V4
U2: LTV-846S; SOIC254P1016X460-16N; PARTREV H

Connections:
+3.3V: R5.2, R6.2, R7.2, R8.2, S1.C, U1.J2-1 (3V3)
+5V: RF2.2, U1.J2-19 (EXT_5V)
+24V: J1.3, J1.4, J1.5, R1.1, R2.1, R3.1, R4.1, R10.1, R11.1
GND: R9.2, R15.2, R16.2, R17.2, U1.J2-14 (GND1), U1.J3-7 (GND2), U2.9, U2.11, U2.13, U2.15
unnamed: D1.1, RF1.1
unnamed: J2.03, R12.1, R13.1
unnamed: C1.1, C2.1, PS1.22 (+VIN), RF1.2
unnamed: PS1.14 (+VOUT), RF2.1
unnamed: C1.2, C2.2, C3.2, J2.01, PS1.2 (-VIN), U2.2, U2.4, U2.6, U2.8
unnamed: C3.1, PS1.16 (-VOUT)
unnamed: R1.2, R2.2, U2.1
unnamed: R3.2, R4.2, U2.3
unnamed: R10.2, R11.2, U2.5
unnamed: R12.2, R13.2, U2.7
unnamed: J2.02, SW1.1 (A)
unnamed: D1.2, SW1.2 (B)
unnamed: R17.1, S1.1, U1.J3-15 (IO2)
unnamed: R16.1, S1.2, U1.J3-13 (IO4)
unnamed: R8.1, U1.J2-12 (IO14), U2.10
unnamed: R15.1, S1.4, U1.J3-12 (IO16)
unnamed: R9.1, S1.8, U1.J3-11 (IO17)
unnamed: R5.1, U1.J2-9 (IO25), U2.16
unnamed: R6.1, U1.J2-10 (IO26), U2.14
unnamed: R7.1, U1.J2-11 (IO27), U2.12

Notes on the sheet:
ESPNOW-SENDER Board Mk2

Board: 2 copper layers, 29 parts (21 on the bottom side), 24 nets, no tracks yet.

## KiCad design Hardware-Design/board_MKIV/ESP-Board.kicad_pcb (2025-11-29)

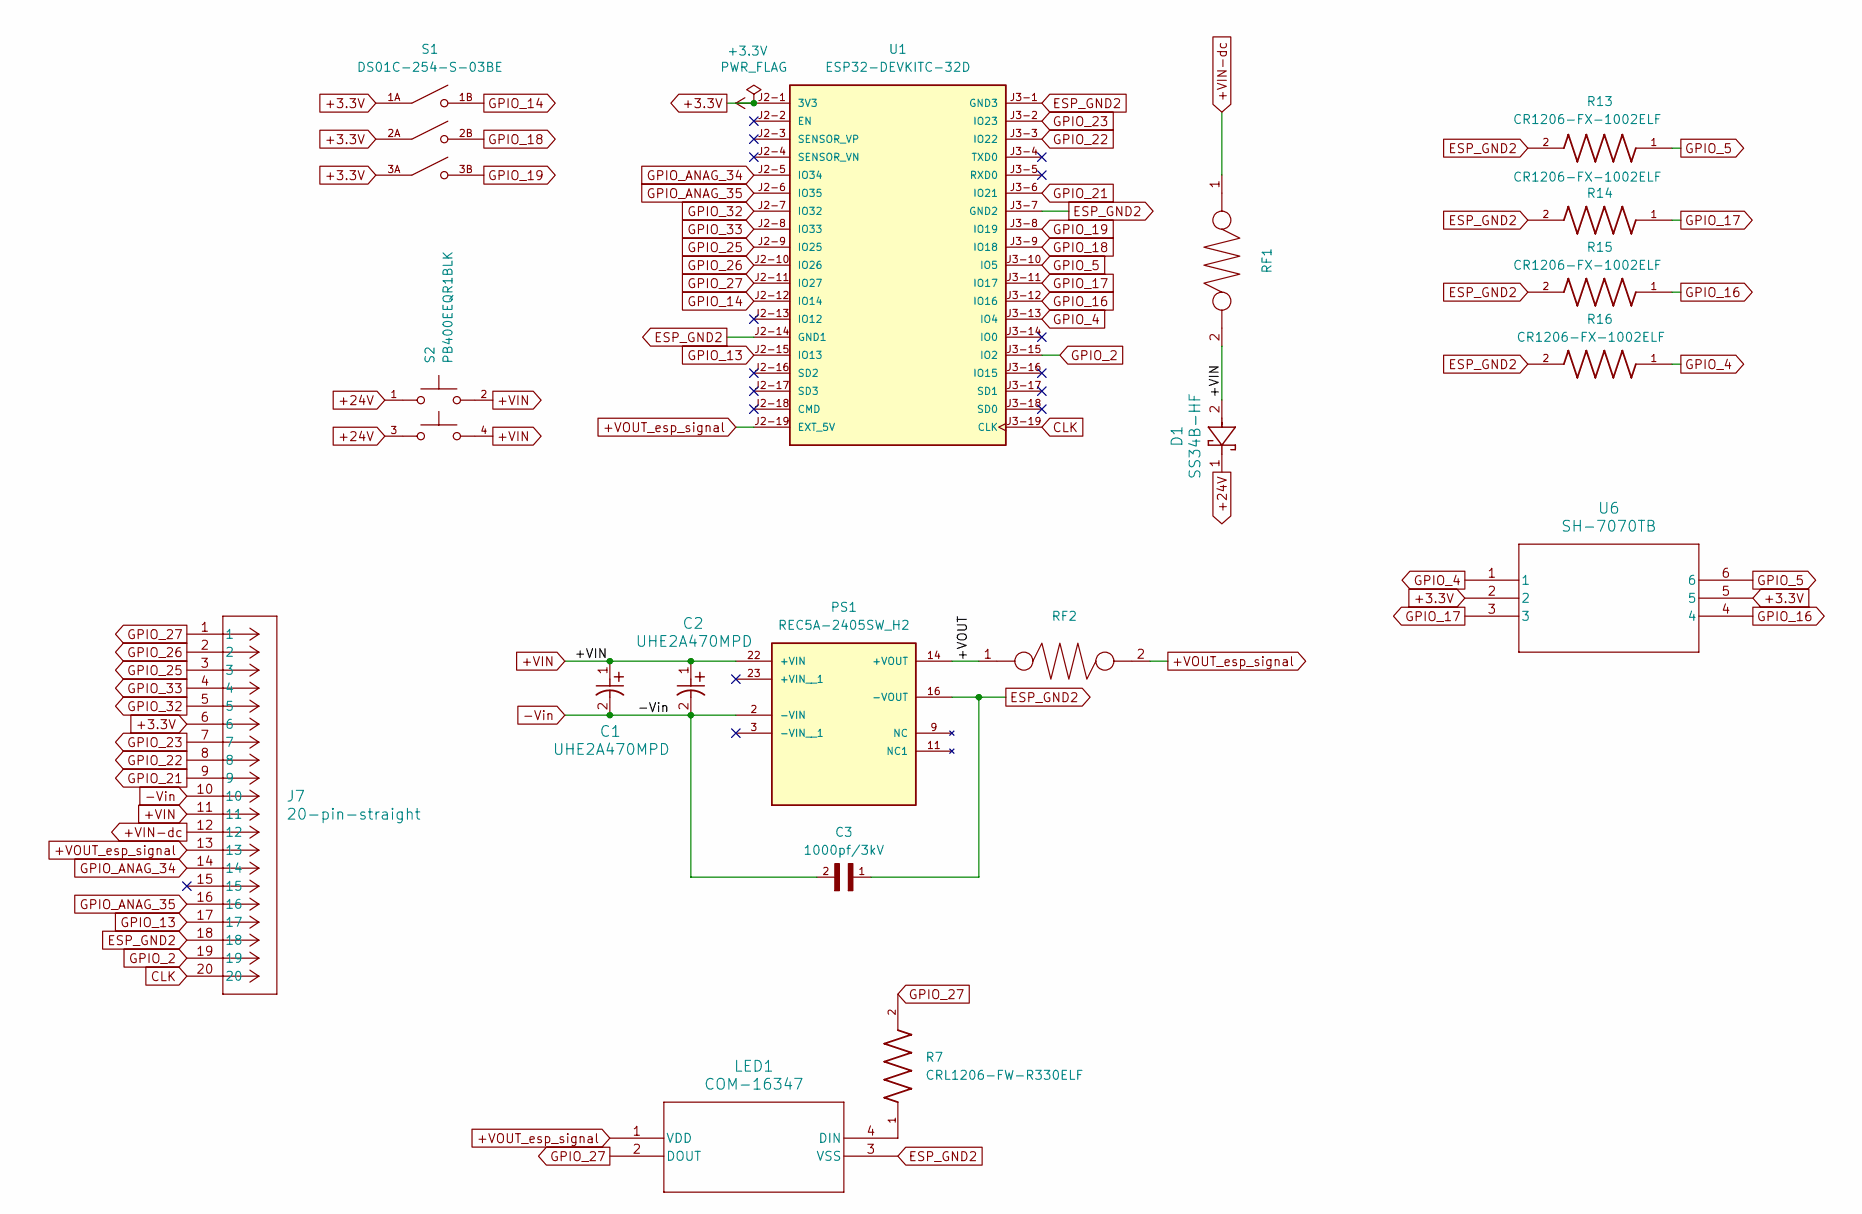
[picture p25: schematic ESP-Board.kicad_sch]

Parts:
C1, C2: UHE2A470MPD; PCAP_10x12_5-THRU-ELECT_NCA
C3: 1000pf/3kV; CAPC3216X180N
D1: SS34B-HF; DO214AASMB_CIP-L
J7: 20-pin-straight; 20_pin_straight
LED1: COM-16347; COM-16347_SPK
PS1: REC5A-2405SW_H2; CONV_REC5A-2405SW_H2; PARTREV N/A
R7: CRL1206-FW-R330ELF; RESC3216X70N
R13, R14, R15, R16: CR1206-FX-1002ELF; RESC3216X75N
RF1, RF2: PTC_RESET_FUSE
S1: DS01C-254-S-03BE; SW_DS01C-254-S-03BE; PARTREV 1.0
S2: PB400EEQR1BLK; SW_PB400EEQR1BLK; PARTREV A
U1: ESP32-DEVKITC-32D; MODULE_ESP32-DEVKITC-32D; PARTREV V4
U6: SH-7070TB; SH-7070TB_7P1X7P3_NDC

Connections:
+3.3V: J7.6, S1.1A, S1.2A, S1.3A, U1.J2-1 (3V3), U6.2, U6.5
+24V: D1.1, S2.1, S2.3
+VIN: C1.1, C2.1, D1.2, J7.11, PS1.22 (+VIN), RF1.2, S2.2, S2.4
+VIN-dc: J7.12, RF1.1
+VOUT_esp_signal: J7.13, LED1.1 (VDD), RF2.2, U1.J2-19 (EXT_5V)
-Vin: C1.2, C2.2, C3.2, J7.10, PS1.2 (-VIN)
/ESP-Board/+VOUT: PS1.14 (+VOUT), RF2.1
CLK: J7.20, U1.J3-19 (CLK)
ESP_GND2: C3.1, J7.18, LED1.3 (VSS), PS1.16 (-VOUT), R13.2, R14.2, R15.2, R16.2, U1.J2-14 (GND1), U1.J3-1 (GND3), U1.J3-7 (GND2)
GPIO_2: J7.19, U1.J3-15 (IO2)
GPIO_4: R16.1, U1.J3-13 (IO4), U6.1
GPIO_5: R14.1, U1.J3-10 (IO5), U6.6
GPIO_13: J7.17, U1.J2-15 (IO13)
GPIO_14: S1.1B, U1.J2-12 (IO14)
GPIO_16: R15.1, U1.J3-12 (IO16), U6.4
GPIO_17: R13.1, U1.J3-11 (IO17), U6.3
GPIO_18: S1.2B, U1.J3-9 (IO18)
GPIO_19: S1.3B, U1.J3-8 (IO19)
GPIO_21: J7.9, U1.J3-6 (IO21)
GPIO_22: J7.8, U1.J3-3 (IO22)
GPIO_23: J7.7, U1.J3-2 (IO23)
GPIO_25: J7.3, U1.J2-9 (IO25)
GPIO_26: J7.2, U1.J2-10 (IO26)
GPIO_27: J7.1, LED1.2 (DOUT), R7.2, U1.J2-11 (IO27)
GPIO_32: J7.5, U1.J2-7 (IO32)
GPIO_33: J7.4, U1.J2-8 (IO33)
GPIO_ANAG_34: J7.14, U1.J2-5 (IO34)
GPIO_ANAG_35: J7.16, U1.J2-6 (IO35)
unnamed: LED1.4 (DIN), R7.1

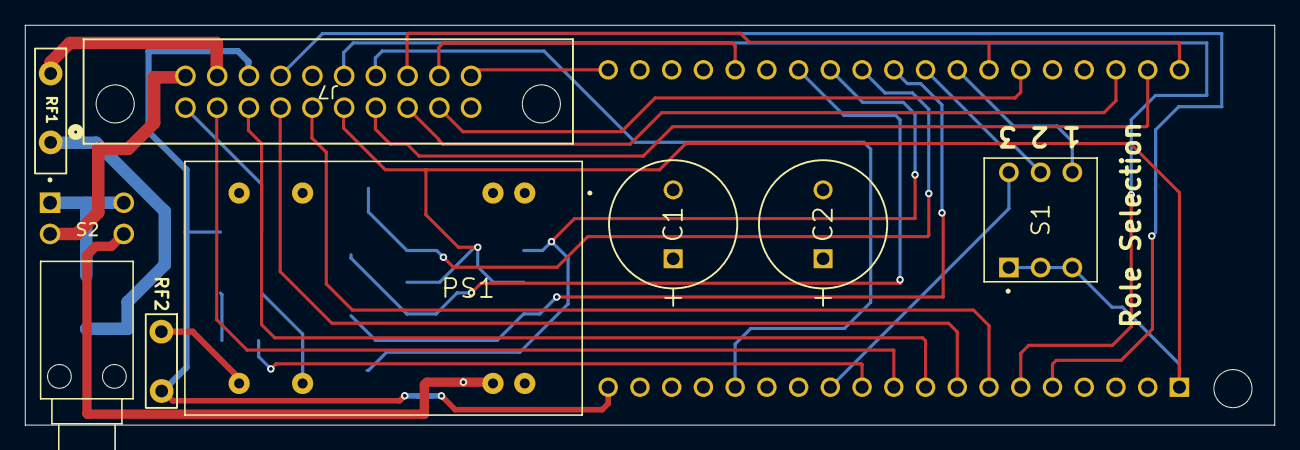
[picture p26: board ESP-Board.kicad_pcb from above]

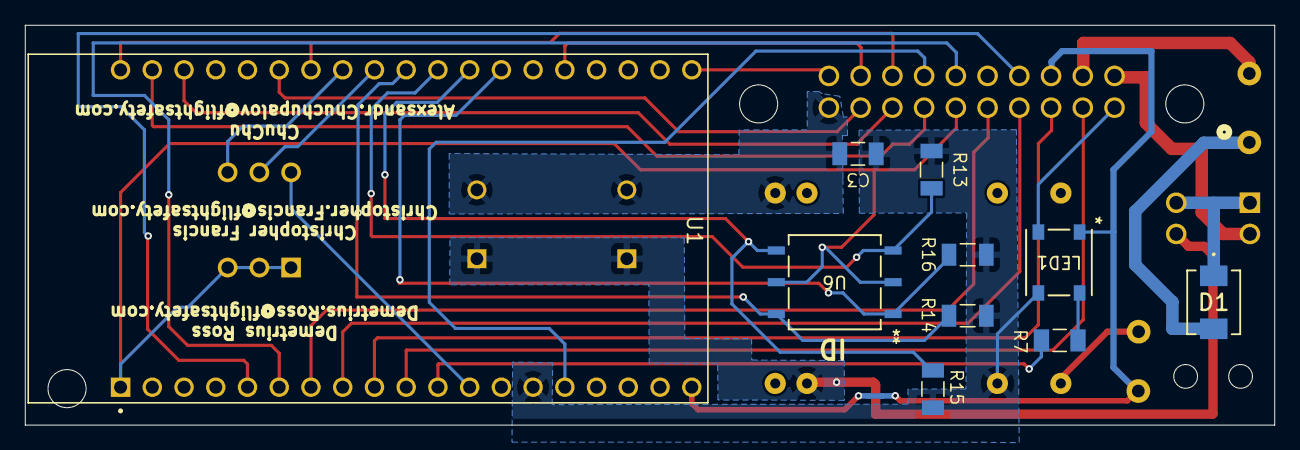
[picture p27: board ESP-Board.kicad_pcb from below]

Board: 2 copper layers, 100.0 x 32.0 mm, 18 parts (10 on the bottom side), 29 nets.

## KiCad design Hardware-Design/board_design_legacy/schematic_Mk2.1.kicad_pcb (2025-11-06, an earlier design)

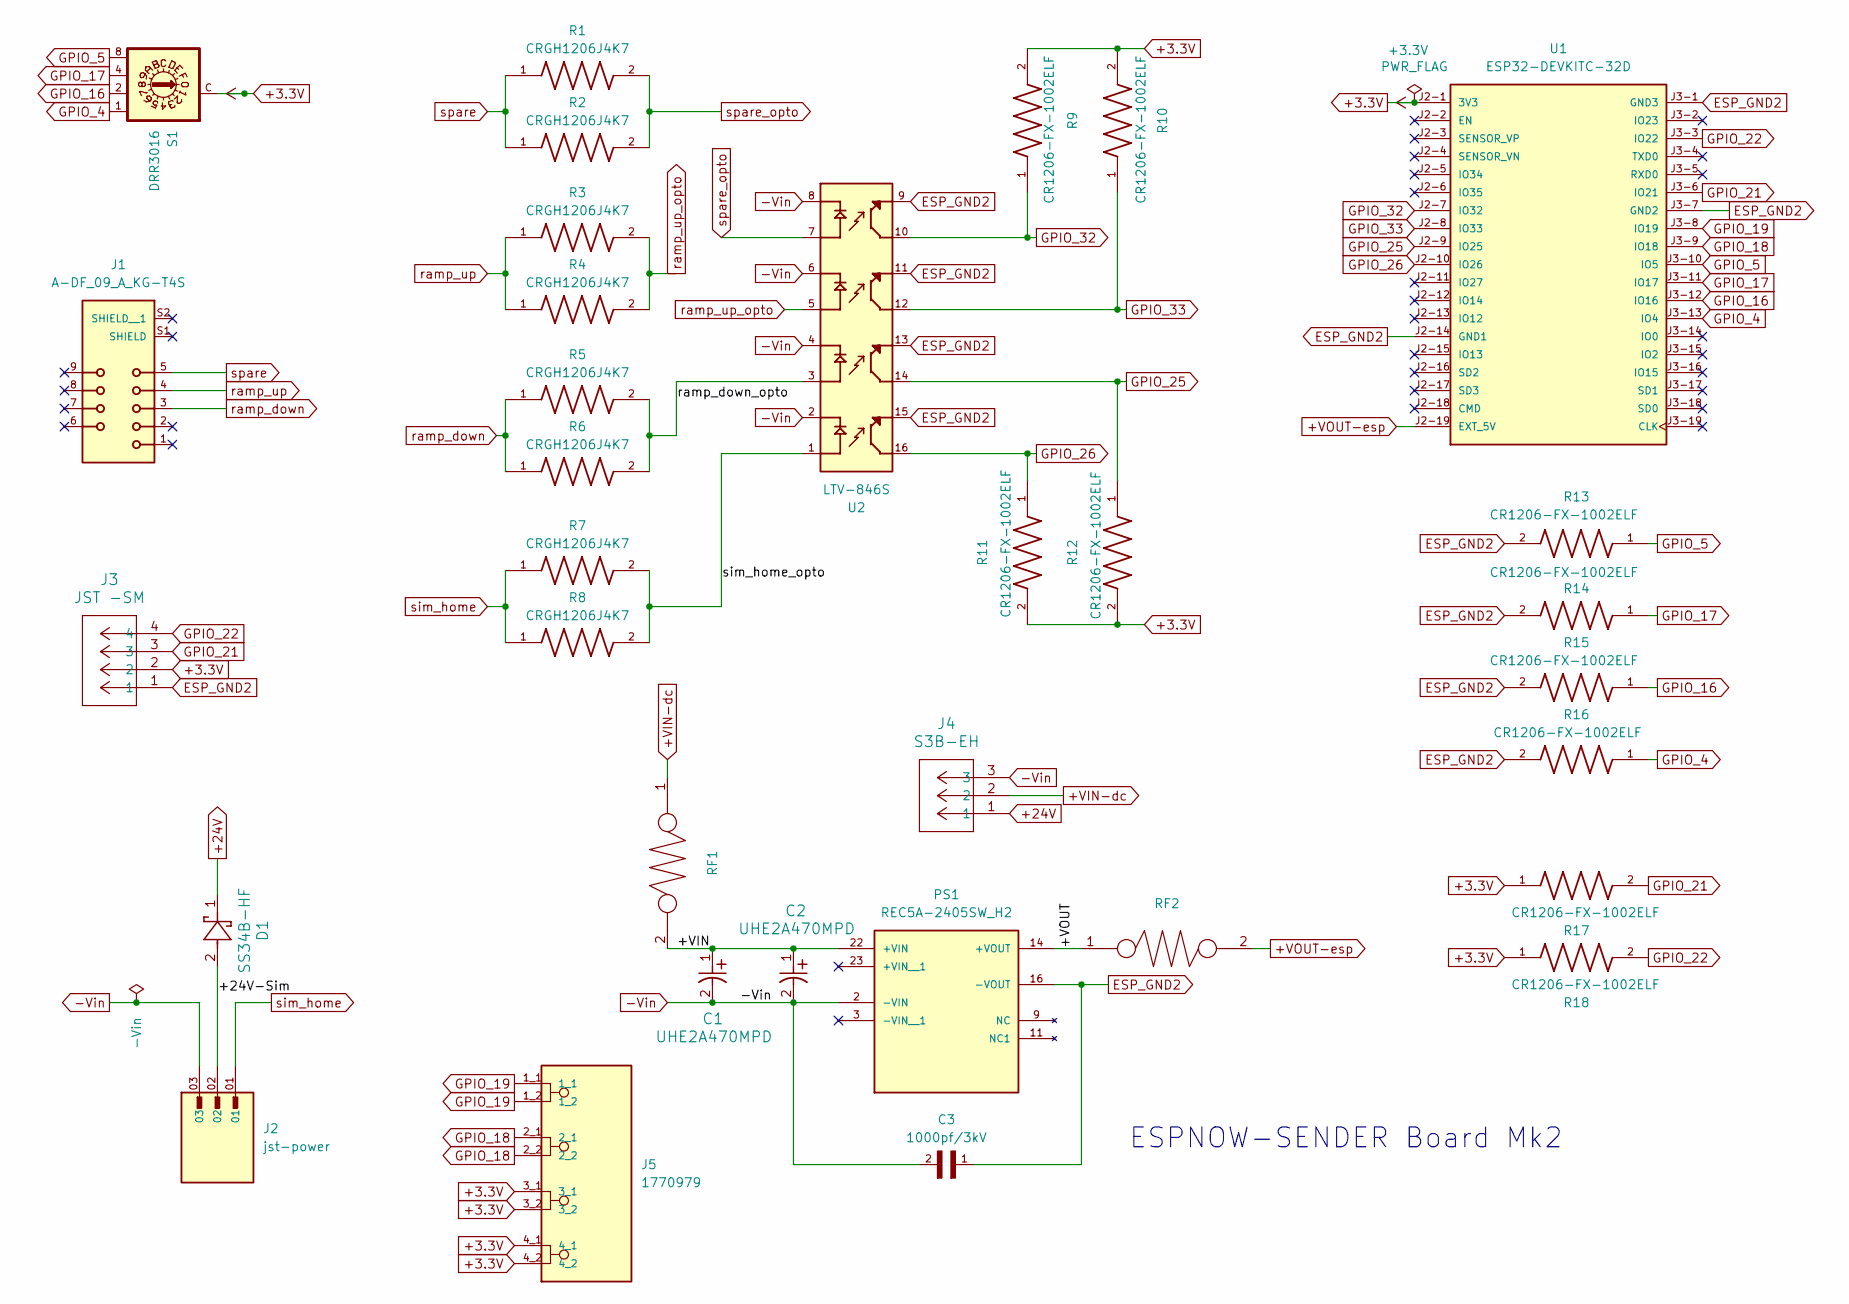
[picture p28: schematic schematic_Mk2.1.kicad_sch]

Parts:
C1, C2: UHE2A470MPD; PCAP_10x12_5-THRU-ELECT_NCA
C3: 1000pf/3kV; CAPC3216X180N
D1: SS34B-HF; DO214AASMB_CIP-L
J1: A-DF_09_A_KG-T4S; ASSMANN_A-DF_09_A_KG-T4S; PARTREV 05
J2: jst-power; PHOENIX_1757255; PARTREV 28.07.2023
J3: JST -SM; CONN_BM04B-SRSS-TB_SPK
J4: S3B-EH; CONN_S3B-EH_JST
J5: 1770979; PHOENIX_1770979
PS1: REC5A-2405SW_H2; CONV_REC5A-2405SW_H2; PARTREV N/A
R1, R2, R3, R5, R6, R7, R8: CRGH1206J4K7; RESC3115X65N
R4: CRGH1206J4K7; RESC3015X65N
R9, R10, R11, R12, R13, R14, R15, R16, R17, R18: CR1206-FX-1002ELF; RESC3216X75N
RF1, RF2: PTC_RESET_FUSE
S1: DRR3016; DRR3010; MPN DRR3016
U1: ESP32-DEVKITC-32D; MODULE_ESP32-DEVKITC-32D; PARTREV V4
U2: LTV-846S; SOIC254P1016X460-16N; PARTREV H

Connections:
+24V: D1.1, J4.1
+VIN-dc: J4.2, RF1.1
+VOUT-esp: RF2.2, U1.J2-19 (EXT_5V)
-Vin: C1.2, C2.2, C3.2, J2.03, J4.3, PS1.2 (-VIN), U2.2, U2.4, U2.6, U2.8
/+24V-Sim: D1.2, J2.02
/+VIN: C1.1, C2.1, PS1.22 (+VIN), RF1.2
/+VOUT: PS1.14 (+VOUT), RF2.1
/ramp_down_opto: R5.2, R6.2, U2.3
/sim_home_opto: R7.2, R8.2, U2.1
GPIO_4: R16.1, S1.1, U1.J3-13 (IO4)
GPIO_5: R14.1, S1.8, U1.J3-10 (IO5)
GPIO_16: R15.1, S1.2, U1.J3-12 (IO16)
GPIO_17: R13.1, S1.4, U1.J3-11 (IO17)
GPIO_18: J1.7, J5.2_1, J5.2_2, U1.J3-9 (IO18)
GPIO_19: J1.6, J5.1_1, J5.1_2, U1.J3-8 (IO19)
GPIO_21: J3.3, R17.2, U1.J3-6 (IO21)
GPIO_22: J3.4, R18.2, U1.J3-3 (IO22)
GPIO_25: R12.1, U1.J2-9 (IO25), U2.14
GPIO_26: R11.1, U1.J2-10 (IO26), U2.16
GPIO_32: R9.1, U1.J2-7 (IO32), U2.10
GPIO_33: R10.1, U1.J2-8 (IO33), U2.12
ramp_down: J1.3, R5.1, R6.1
ramp_up: J1.4, R3.1, R4.1
ramp_up_opto: R3.2, R4.2, U2.5
sim_home: J2.01, R7.1, R8.1
spare: J1.5, R1.1, R2.1
spare_opto: R1.2, R2.2, U2.7

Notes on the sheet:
ESPNOW-SENDER Board Mk2

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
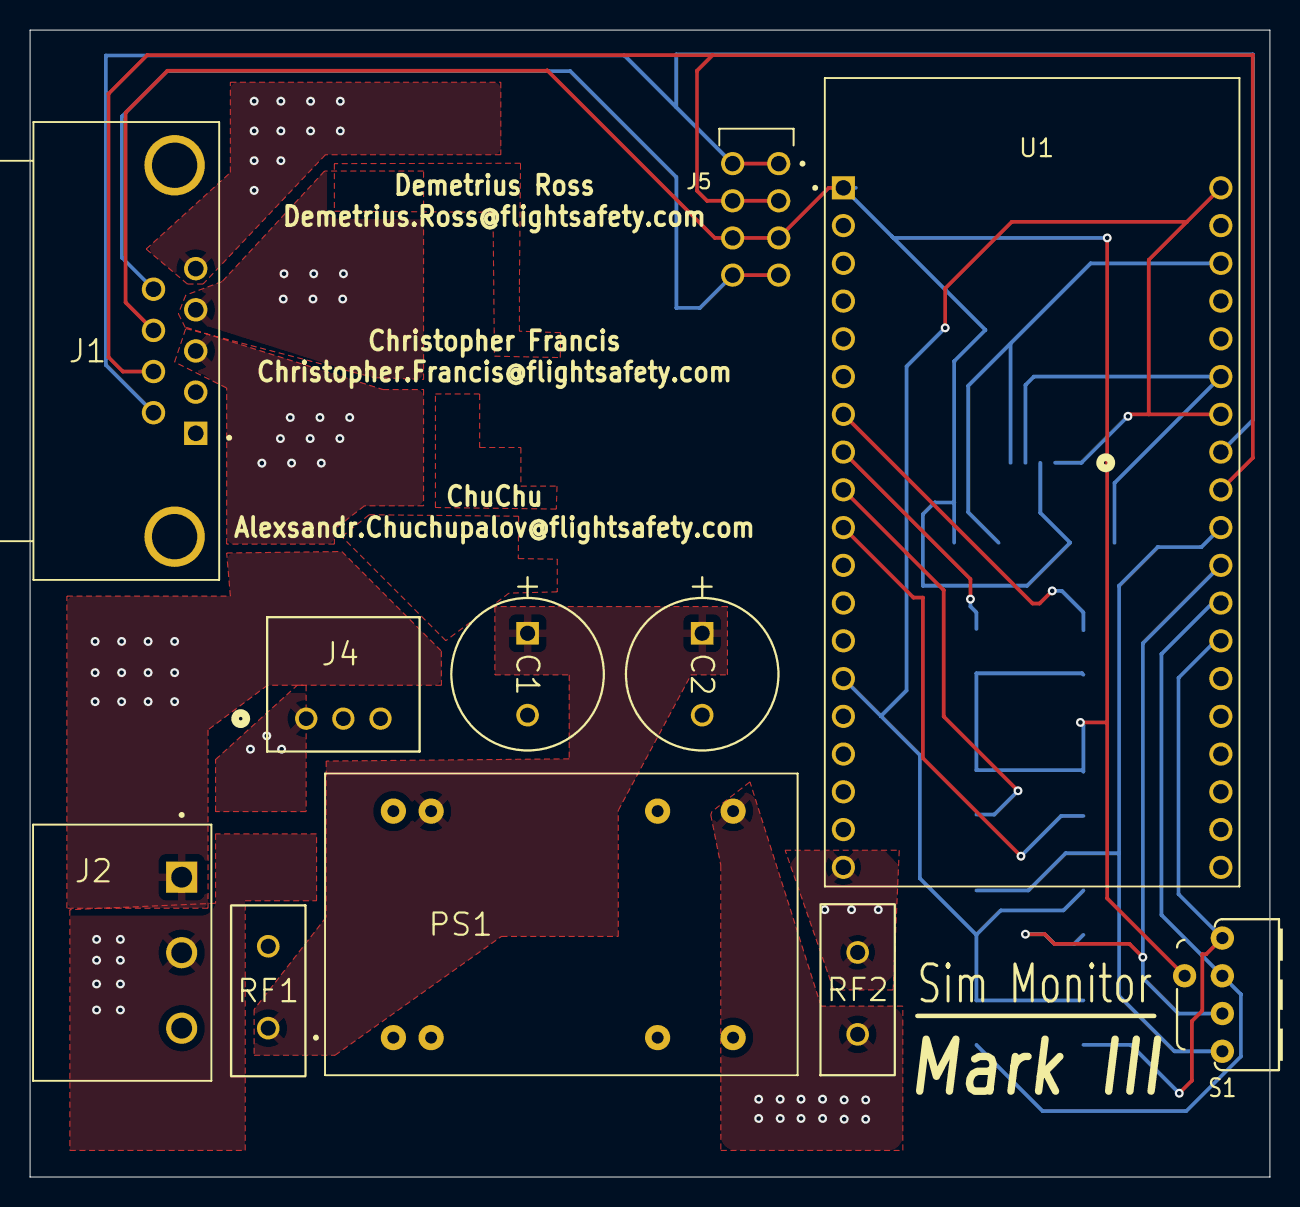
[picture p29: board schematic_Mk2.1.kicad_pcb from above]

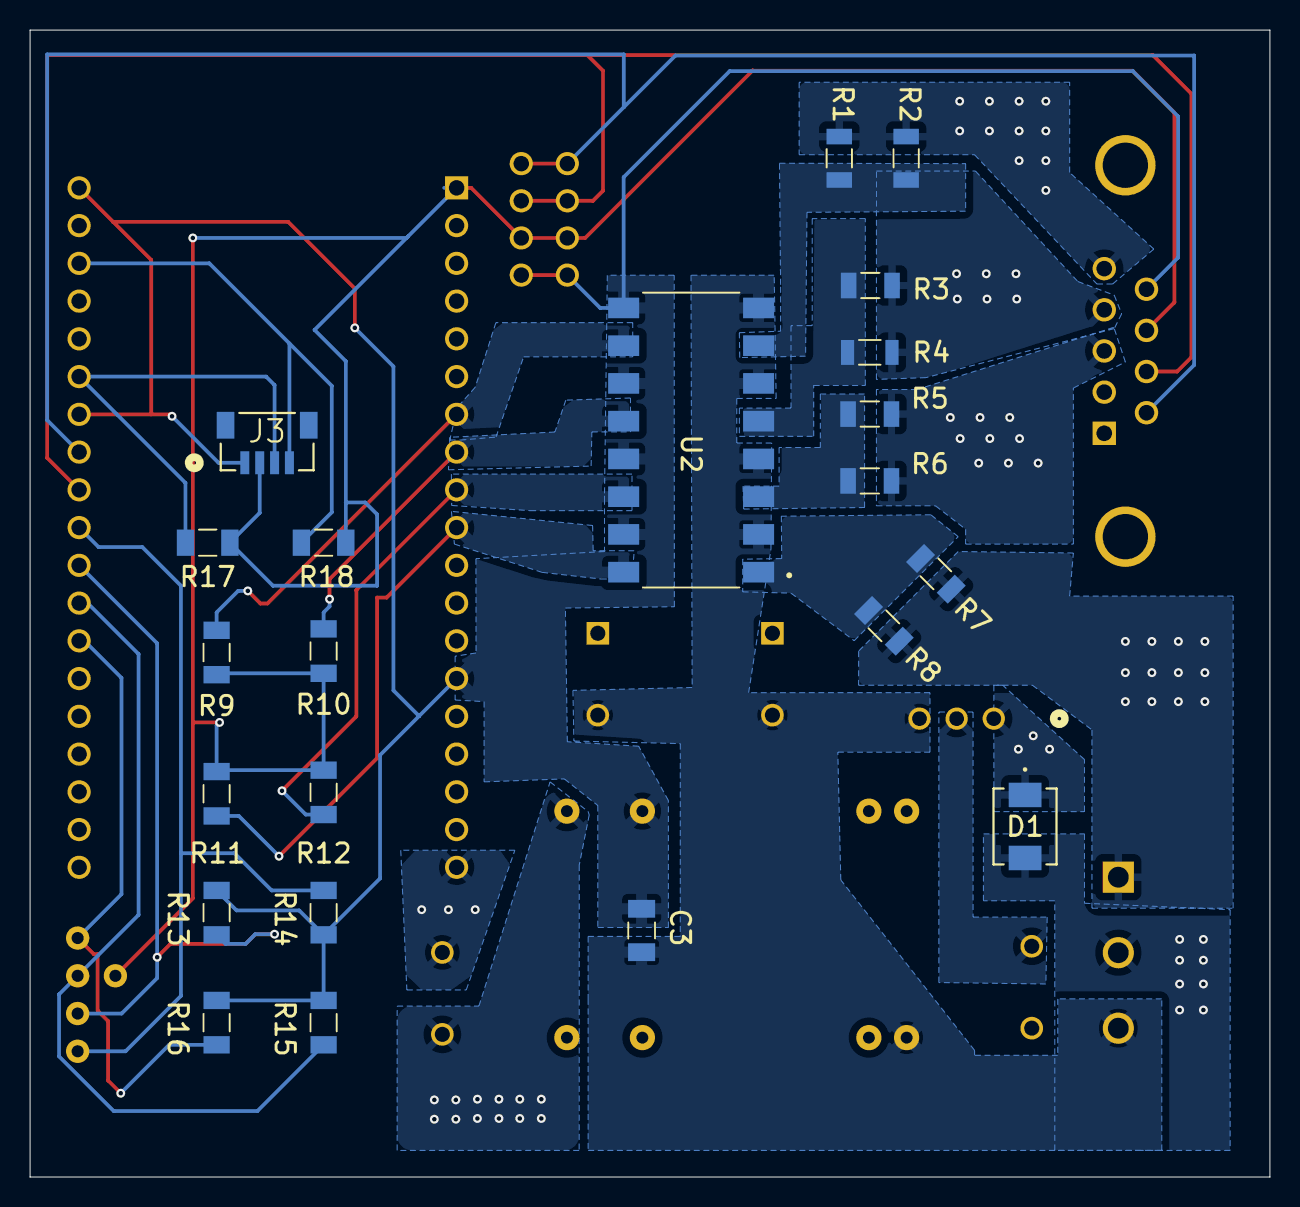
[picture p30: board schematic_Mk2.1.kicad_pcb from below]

Board: 2 copper layers, 83.4 x 77.2 mm, 33 parts (22 on the bottom side), 29 nets.

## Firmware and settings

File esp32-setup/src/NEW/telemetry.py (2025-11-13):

from machine import Pin, I2C
import time
import math
import onewire
import ds18x20
import ssd1306

# ========== OLED SETUP ==========
OLED_WIDTH  = 128
OLED_HEIGHT = 32
SDA_PIN  = 21
SCL_PIN  = 22

i2c = I2C(0, scl=Pin(SCL_PIN), sda=Pin(SDA_PIN), freq=400_000)
devices = i2c.scan()
print("I2C scan:", devices)

if 0x3C not in devices:
    print("ERROR: OLED not found!")
else:
    print("OLED detected at 0x3C")

oled = ssd1306.SSD1306_I2C(OLED_WIDTH, OLED_HEIGHT, i2c)

# Clear screen safely
def oled_print(lines):
    oled.fill(0)
    y = 0
    for line in lines:
        oled.text(line, 0, y)
        y += 12
    oled.show()


# ========== DS18B20 SETUP ==========
TEMP_PIN = 19
ow = onewire.OneWire(Pin(TEMP_PIN))
ds = ds18x20.DS18X20(ow)
roms = ds.scan()
print("DS18B20 ROMs:", roms)

if not roms:
    raise RuntimeError("No DS18B20 temperature sensors found!")


# ========== ADXL345 CONSTANTS ==========
ADXL345_ADDR = 0x53
REG_DEVID       = 0x00
REG_BW_RATE     = 0x2C
REG_POWER_CTL   = 0x2D
REG_DATA_FORMAT = 0x31
REG_DATAX0      = 0x32
REG_INT_ENABLE  = 0x2E
REG_INT_MAP     = 0x2F
REG_INT_SOURCE  = 0x30


# ========== ADXL345 DRIVER ==========
class ADXL345:
    def __init__(self, i2c, addr=ADXL345_ADDR):
        self.i2c = i2c
        self.addr = addr

        devid = self.read_reg(REG_DEVID)
        print("ADXL345 DEVID: 0x{:02X}".format(devid))
        if devid != 0xE5:
            print("WARNING: ADXL345 not detected")

        self.write_reg(REG_BW_RATE, 0x0A)        # 100 Hz
        self.write_reg(REG_DATA_FORMAT, 0x08)    # FULL_RES, ±2g
        self.write_reg(REG_POWER_CTL, 0x08)      # Measure mode

        print("ADXL345 ready.\n")

    def write_reg(self, reg, value):
        self.i2c.writeto_mem(self.addr, reg, bytes([value]))

    def read_reg(self, reg):
        return int.from_bytes(self.i2c.readfrom_mem(self.addr, reg, 1), "little")

    def read_xyz_raw(self):
        data = self.i2c.readfrom_mem(self.addr, REG_DATAX0, 6)

        def s16(lo, hi):
            v = lo | (hi << 8)
            return v - 65536 if v & 0x8000 else v

        x = s16(data[0], data[1])
        y = s16(data[2], data[3])
        z = s16(data[4], data[5])
        return x, y, z

    def read_xyz_g(self):
        x, y, z = self.read_xyz_raw()
        scale = 0.0039
        return x * scale, y * scale, z * scale

    def compute_angles(self):
        x, y, z = self.read_xyz_g()
        norm = math.sqrt(x*x + y*y + z*z)
        if norm == 0:
            return 0, 0, 0

        roll  = math.atan2(y, z)
        pitch = math.atan2(-x, math.sqrt(y*y + z*z))
        tilt  = math.acos(z / norm)
        return math.degrees(roll), math.degrees(pitch), math.degrees(tilt)


# ========== ACCELEROMETER & INTERRUPTS ==========
INT1_PIN = 18
INT2_PIN = 5  # <— safer, since DS18B20 uses 19

int1 = Pin(INT1_PIN, Pin.IN, Pin.PULL_UP)
int2 = Pin(INT2_PIN, Pin.IN, Pin.PULL_UP)

def int1_handler(pin):
    print("[INT1] Accelerometer interrupt!")

def int2_handler(pin):
    print("[INT2] Accelerometer interrupt!")

int1.irq(trigger=Pin.IRQ_FALLING, handler=int1_handler)
int2.irq(trigger=Pin.IRQ_FALLING, handler=int2_handler)

adxl = ADXL345(i2c)


# ========== MAIN LOOP ==========
while True:
    # --- Temperature ---
    ds.convert_temp()
    time.sleep_ms(750)

    try:
        temp_c = ds.read_temp(roms[0])
        temp_f = temp_c * 9/5 + 32
    except:
        temp_c = None
        temp_f = None

    # --- Accelerometer ---
    xg, yg, zg = adxl.read_xyz_g()
    roll, pitch, tilt = adxl.compute_angles()

    # SERIAL PRINT
    print("\n=== SENSOR DATA ===")
    print("Temp: {:.2f}C  {:.2f}F".format(temp_c, temp_f))
    print("Acc: X={:.2f}g  Y={:.2f}g  Z={:.2f}g".format(xg, yg, zg))
    print("Angles: Roll={:.1f}° Pitch={:.1f}° Tilt={:.1f}°".format(
        roll, pitch, tilt
    ))

    # OLED DISPLAY
    oled_print([
        "T: {:.1f}C / {:.1f}F".format(temp_c, temp_f),
        "X:{:.2f}g Y:{:.2f}g".format(xg, yg),
        "Z:{:.2f}g".format(zg),
        "R:{:.1f} P:{:.1f}".format(roll, pitch),
        "Tilt:{:.1f}deg".format(tilt)
    ])

    time.sleep(0.2)

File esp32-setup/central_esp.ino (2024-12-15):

#include <esp_now.h>
#include <WiFi.h>

// Data structure to receive
typedef struct {
  char simName[10]; // Simulator name
  int rampState;    // 0: In motion, 1: Ramp Up, 2: Ramp Down
  int motionState;  // 1: Sim Down (Home), 2: Sim Up
  int status;       // 0: No Data, 1: Connected
} Message;

Message incomingData;

// Callback function for ESP-NOW
void onDataRecv(const esp_now_recv_info_t *recv_info, const uint8_t *incomingData, int len) {
  // Validate the data length
  if (len != sizeof(Message)) {
    Serial.println("Error: Invalid data size received!");
    return;
  }

  // Cast the incoming data to our structure
  const Message *receivedData = (const Message *)incomingData;


  // Forward the data to the Raspberry Pi via Serial
  Serial.print(receivedData->simName);
  Serial.print(",");
  Serial.print(receivedData->rampState);
  Serial.print(",");
  Serial.print(receivedData->motionState);
  Serial.print(",");
  Serial.println(receivedData->status);
}

void setup() {
  Serial.begin(115200); // Open serial communication with Raspberry Pi

  // Initialize Wi-Fi in station mode
  WiFi.mode(WIFI_STA);

  // Initialize ESP-NOW
  if (esp_now_init() != ESP_OK) {
    Serial.println("Error initializing ESP-NOW");
    return;
  }

  // Register the receive callback
  esp_now_register_recv_cb(onDataRecv);

  Serial.println("Main ESP ready to forward messages.");
}

void loop() {
  // Nothing to do in the main loop; data is handled in the callback
}

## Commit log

2024-12-03 led update
2024-12-04 Pin Update
2024-12-12 invert led
2025-02-17 Relay Update
2025-03-06 buck converter update
2025-03-11 pcb update
    [final-pcb.kicad_pcb, sim-monitor-sd.csv, sim-monitor-sd.kicad_sch]
2025-04-04 updated schematics
    [MP2315GJ-Z.STEP, REC5A-2405SW_H2.step, RNCP1206FTD1K10.step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]
2025-04-04 schematic update
    [A-DF_09_A_KG-T4S.step, C1206C104K4RACTU.step, CR1206-FX-1002ELF.step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]
2025-04-05 updated schematic
    [schematic_V2.kicad_sch]
2025-04-12 PCB updated
    [schematic_Mk2.1.kicad_pcb, schematic_Mk2.1.kicad_sch, schematic_Mk2.kicad_pcb]
2025-04-15 updating board
    [schematic_Mk2.kicad_pcb]
2025-05-06 board update
    [schematic_Mk2.1.kicad_pcb]
2025-05-21 id updates
    [schematic_Mk2.1.csv]
2025-11-06 Board MKIV init
    [1757242.step, 1757255.stp, 1770979.step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]
2025-11-29 MKIV Update
    [1757242.step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]
2026-01-03 Jan Update
    [1757255.stp, 1770979.step, 1989764.step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]
